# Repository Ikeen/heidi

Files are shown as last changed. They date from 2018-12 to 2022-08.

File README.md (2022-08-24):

# heidi heidi logo Heidi
GPS tracking system for alpine pasture - or simply sheeps :-)

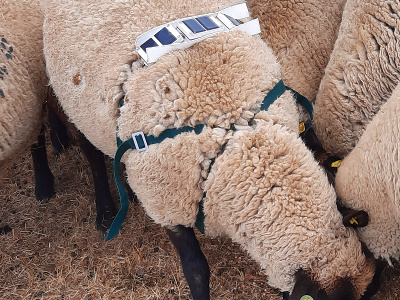
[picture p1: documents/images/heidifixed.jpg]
heidi fixed Heidi


## Table of contents
* [Licence info](#licence-info)
* [Project](#project)
* [Milestones](#milestones)
* [Solutions](#solutions)
* [News](#news)

## Licence info

You may freely use or copy this project under the following conditions:

* non-commercial use
* no warranties
	
## Project

The project goal:

* creating a tracker system from scratch
* using free available cheap standard electronic components
* 3D printable housings
* with in situ solar power generation for continuous operation
* vitality monitoring
* local LoRa network with client tracker modules for individual animal monitoring
	
## Milestones

* functional prototype - done
* CAD work for housings - done 
* initial web service - done
* 1st gateway tracker module for testings - done
* endurance tests for housing, power supply and modul reliability - done
* 1st client tracker module for testings - done
* endurance tests for lokal LoRa netwok reliability (gateway tracker <-> client trackers) - done
* accelerometer for vitality monitoring - done
* geofencing functionality - done
* store configuration data into flash memory - tbd
* tool for programming configuration data into flash memory - tbd

## Solutions

some solutions to various problems

* sending data via GSM cause Arduino to crash: Try another orientation of GSM-antenna. Sometimes a piece of copper acts like a receiving antenna, what may have an impact on the Arduino board.
* sending / getting data via GSM is unreliable: Check power connection to battery, MOSFET, DC-DC-Converter - they should be strong. In my case I soldered wires directly to IC-pins.
* serial communication between components produces strange characters: internally pullup RX-wire with "pinMode(_RXD, INPUT_PULLUP);". The HardwareSerial library seems not to do that. Most time it works without dedicated pullup - sometimes it doesn't.
* never place GSM-antenna and DC-DC-converter near by together

## News

* after various problems with communication reliability - especially with low battery - we find out, that placing a additional big capacitor on the power input of the DC-DC-converter, solves a buck of problems. It seems we can even omit the backup battery when we do so - but the DC-DC-converter is still needed. The SIM800L module will not work properly with less then 3.8V - even if the manual tells: it will.
* the fixing via belt clip turned out to be not reliable. We went back to the first intended fixing by screwing the hard plastic parts directly to a belt. Description and pictures coming soon on this channel.
* the buffer battery on the GPS module empties within a few days due to the way we use it. Let me explain a little more: keep the GPS module in power save tracking mode will give us quick results (saving time saves power) but it still draws about 10mA, way too much - so we completely cut it off from power. Usually the buffer battery enables the module to backup some information about the last position lock. These information eases and speeds up the next position lock. Unfortunately the battery is weak and its charging to slow, so it will be discharged after a couple of days. Removing the Battery from module and connecting the backup-pin of the UBLOX to 3.3V from Arduino will solve that problem and we will significantly profit from the backup function. The backup draws about 15uA - no problem. Assembly instructions and sketches will be updated soon. (done)
* the battery solar charging modules in Heidi hardware version 1 and 2 have one or two small big problems: if they are, for what reason ever, shortly disconnected from battery, sometimes they may be unable to reconnect the load to the battery. Furthermore their thresholds of hysteresis (deep discharge protection) are too low, so if the voltage goes too low ESP32 will boot in a circle until the modules cut off from load due to under voltage. So far so good, but in case of recharged batteries they will reconnect the load too early, so the ESP32 will directly starts with booting in a circle until the voltage is too low again. We've decided to implement a own protection circuit which cuts off on 2.7V and reconnects on 3.0V. That will keep the ESP32 in save states. Additionally that means, we can use Modules without under voltage protection. BUT: Doing this we loose short circuit protection too. We strongly recommend batteries with included protection PCB. (no barbecue on pasture!)

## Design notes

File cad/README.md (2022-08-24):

# heidi - cad
Some CAD- and 3D-printing hints

## Table of contents
* [CAD](#cad)
* [3D-printing](#3d-printing)
  * [Printing direction](#printing-direction)
  * [Dealing with ASA-filament](#dealing-with-asa-filament)
  * [Warping](#warping)
  * [Solutions](#solutions)
  * [Notes](#notes)
* [Schmitt-Trigger](#schmitt-trigger)
  * [KiCad](#kicad)
  * [Get a PCB](#get-a-pcb)
  * [Electronic parts](#electronic-parts)

## CAD
All CAD was done with [FreeCad](https://www.freecad.org/). All CAD project files are uploaded too (*.fcstd).

## 3D-printing
For our purposes we decided to use 3D print for building up housings. This is flexible and cost efficient. For more reliability against weather and mechanical stress it would be better to use housings milled from the solid material. There are good offers for 3-axis CNC mills - maybe we will test this later on. (It seems we seriously need to talk to Santa regarding this. :-D )
### Printing direction
For mechanical reasons you need to consider printing direction. 3D printed objects do have less mechanical strength in vertical printing direction, so the orientation of objects during printing process matters. You may use the models or *.stl files with number 3 in the file name to get models already ready for printing. Most of them are doubled and connected by thin walls, to get a stable printing process.
### Dealing with ASA-filament
The outdoor usage of Heidi-Tracker requires a weather proofed housing material. We decided for ASA-filament from PolyMaker (for no special reasons). If you not own a industrial like 3D-printer, printing ASA-filament is not quite simple. The temperature for the material nozzle and the build plate (bed) needs to be adjusted depending on the geometry of the part you intend to print. (As far as we discovered due to many tries.)
### Warping
[(warping - see here)](https://support.ultimaker.com/hc/article_attachments/360009279100/How_to_fix_warping_Warping_model.jpg)<br />
Warping is the main issue while printing ASA filament. There are many hints you can find in the internet to fix warping. 

### Solutions
some solutions to various problems
* to minimize warping you may use a frame, like the one in the picture below, together with at least 20 brim lines. 
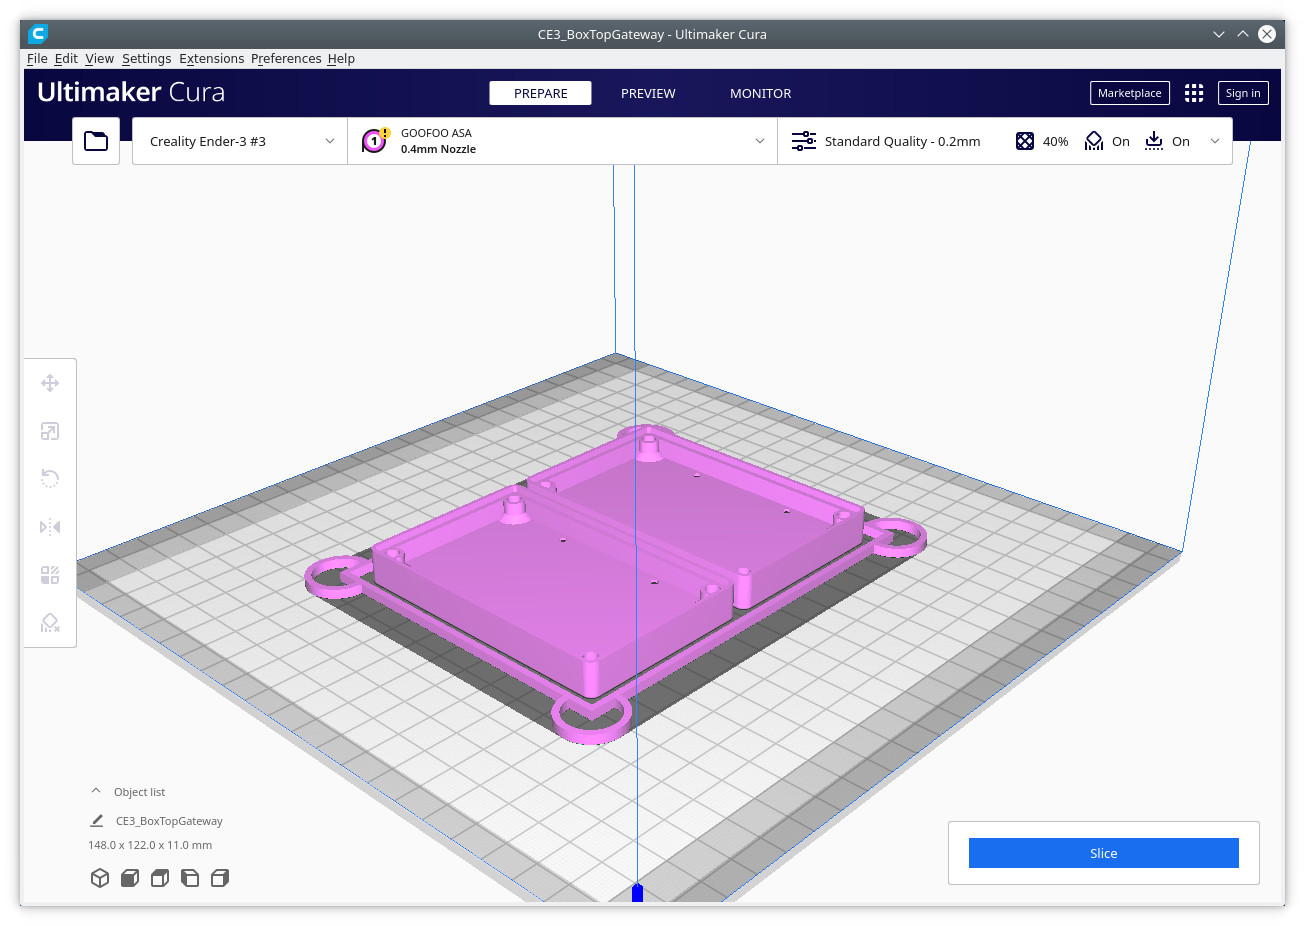
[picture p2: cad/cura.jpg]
Cura


### Notes
* There are slightly different sizes of GPS-antenna boards used. Currently GPSAntennaClip is for the bigger one (28mm edge length), GPSAntennaClip3 is for the smaller one (25mm edge length) 

## Schmitt-Trigger
As mentioned in the introducing README, the cut-off threshold of the battery protection circuits (2.4 volts) is too low and leads heidi into a dead lock if the voltage goes below 2.6 volts. Therefore we decided to create a own protection circuit, which cuts off at about 2.8 volts and brings heidi back to power at about 3.1 volts. That ensures, that the ESP32 works correctly (when empowered). (By the way: It's our first own PCB - it was a huge fun to research, learn to calculate a Schmitt-Trigger, to test, to explore new CAD-software...)

Keep in mind: You nevertheless need a battery protection circuit. The Schmitt-Trigger will continously draw a small current too. We decided to use LiPo batteries with [included protection](https://www.trustfire.com/collections/batteries/).

### KiCad
The software we're using for schematics an PCB layout is [KiCad](https://www.kicad.org). You find the project files unter /SchmittTrigger. 

### Get a PCB
The PCB has just one layer and no throughplatings - even for the power connections, what saves costs. The gerber files, needed for ordering PCBs online, are in the zip file. We've ordered the PCB [here]( https://aisler.net) -  good price, quick service. 

### Electronic parts
Be sure to use a dual channel rail to rail operational amplifier with a minimum operation voltage of 2.7 volt. Keep an eye on its supply current - it should be less as possible. The P-channel FET is a power-FET, but maybe another will do too, because there are just a few milliamps to manage.

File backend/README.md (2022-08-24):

# heidi-backend
We're (still) working with Eclipse 2018-12 (4.10.0) and the (old 1.0.5) CDT-libraries by espressif. You can find the reason [here](https://github.com/frankheisig71/TestAccel).
So here you will find the instructions to setup Eclipse 2018 with Arduino-CDT libraries on a Linux machine to build the heidi firmware. You are free to use another dev environment or other versions and to adopt the installation steps.

## Table of contents
* [Install Eclipse](#install-eclipse)
* [Install ESP32 core libs](#esp32-core-libs)
* [Install tool chain](#toolchain)
* [Edit platform.txt](#platform.txt)
* [Change Java version](#java)
* [Add ESP32 libs](#esp32-libs)
* [Enable phyton-serial](#phyton-serial)

## Install Eclipse
* Get Eclipse 4.10 from
https://archive.eclipse.org/eclipse/downloads/drops4/R-4.10-201812060815/ and install it to a directory of your choice.
* Start the executable.
* go to Help -> Install New Software, press "Add" and install download.eclipse.org/mpc/photon as a new repository.
* after downloading, check the selection box -> Next -> Next -> accept -> Finish (installation may take some time)
* restart Eclipse
* go to Help -> Eclipse Marketplace, search for "espressif"
* install "Eclipse C++ IDE for Arduino" (be patient)

## Install ESP32 core libs
* get https://github.com/espressif/arduino-esp32/releases/download/1.0.5/esp32-1.0.5.zip
* copy zip content to ~/.arduinocdt/packages
* get https://github.com/espressif/arduino-esp32/releases/download/1.0.5/package_esp32_index.json and put it to ~/.arduinocdt

## Install tool chain
* check the needed toolchain by opening package_esp32_index.json and searching "platforms": -> "architecture": "esp32", "version": "1.0.5" -> "toolsDependencies" -> "name". In our case it is:  "xtensa-esp32-elf-gcc". Note the needed version. For our case it is: "1.22.0-97-gc752ad5-5.2.0".
* now find the link to the toolchain for your operating system by searching for '"tools": ['. Find the right toolchain ("name") with the right version ("version") -> find the right operating system. For our case it is: ""x86_64-pc-linux-gnu"
* get the package following the link under "url". For our case it is: "https://github.com/espressif/arduino-esp32/releases/download/1.0.5-rc5/xtensa-esp32-elf-linux64-1.22.0-97-gc752ad5-5.2.0.tar.gz"
* extract the tar archive - next we need to copy the content of the root folder from the extracted archive, WITHOUT the root folder
* copy the content to ~/.arduinocdt/packages/esp32/tools/%name%/%version%. For our case it is: ~/.arduinocdt/packages/esp32/tools/xtensa-esp32-elf-gcc/1.22.0-97-gc752ad5-5.2.0/
* do exact the same steps the other toolsDependencies under "platforms": (In our case: "esptool_py" and "mkspiffs") with similar path name structure
* check the symlinks under ~/.arduinocdt/packages/esp32/tools/%name%/%version%/xtensa-esp32-elf (usually they are okay)

## Edit platform.txt
* open ~/.arduinocdt/packages/esp32/esp32/hardware/esp32/1.0.5/platform.txt
* seach for: `## Create partitions.bin`
* comment out: `recipe.objcopy.partitions.bin.pattern={tools.gen_esp32part.cmd} -q "{build.path}/partitions.csv" "{build.path}/{build.project_name}.partitions.bin"`
* insert: `recipe.objcopy.eep.pattern={tools.gen_esp32part.cmd} -q "{runtime.platform.path}/tools/partitions/{build.partitions}.csv" "{build.path}/{build.project_name}.partitions.bin"`
* seach for: `runtime.tools.xtensa-esp32-elf-gcc.path =`
* if found, change it to: `runtime.tools.xtensa-esp32-elf-gcc.path = ~/.arduinocdt/packages/esp32/tools/xtensa-esp32-elf`
* seach for: `runtime.tools.esptool.path =`
* if found, change it to: `runtime.tools.esptool.path = ~/.arduinocdt/packages/esp32/tools/esptool`

## Change Java version
* java version for Eclipse 2018 is 1.11
* open eclipse.ini search for: `-vmargs`
* add or change before `-vmargs`: <br>
  `-vm`<br>
  `/usr/lib/jvm/java-1.11.0-openjdk-amd64/bin/java`
* (... or whereever java is installed)

## Add ESP32 libs
* Open Eclipse and go to Help -> Arduino Downloads Manager -> Libraries

For Heidi we need:

* ESP8266 and ESP32 OLED driver for SSD1306 displays
* LoRa
* OneWire
* DallasTemperature
* FEC Reed-Solomon

## Enable phyton-serial
Linux users need to put themselves into the dialout group
* `sudo apt install python-serial`
* `sudo adduser [user] dialout`

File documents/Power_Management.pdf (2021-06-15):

Power management of the Heidi tracker

The Arduino is powered by 2 batteries. On one hand the regular board voltage supply and on the other hand a backup battery, which prevents a brown-out of the Arduiono due to voltage drops caused by the high peak currents of the GSM module from a board voltage of Ubatt < approx. 3.8V. Both supply lines are connected via a current switch, 2 Schottky diodes. This circuit leads to a equal voltage discharging of both batteries. .

So the Arduino gets its supply voltage via 1 Schottky diode of type 1N5817 each. This diode has a voltage loss of about 0.3V in forward direction, which means that Ubatt - 0.3V arrives at the Arduino.

The ESP32 works correctly down to about 2.6V, as far as no internal consumers like GPIO's need additional current. As soon as the power consumption increases just a little bit, a brownout reset may occur (a big capacitor does not change this bevavior).

In the range below 2.6V the behavior of the ESP32 is undetermined - it boots in a circle.

The deep discharge protection of the solar loader modules cuts the load from the batterie at Ubatt < 2.4V and switches it on again at Ubatt ≥ 3.0V.

The following voltage limits are fixed:

- Ubatt ≥ 3,6V | – normal function
- 3,6V > Ubatt ≥ 3,5V – doubled times between regular data transmissions, alarms
| normal
- 3,5V > Ubatt ≥ 3,4V – no regular data transmissions, alarms normal
- Ubatt < 3,4V | – deep sleep for 15 minutes
- Ubatt < 3,3V | – deep sleep for 60 minutes

The aim of the power management is to be able to send alarms as long as possible when the batteries are underpowered and to avoid a supply voltage of the Arduino below 2.6 V later on.

From 3.5 V battery voltage the battery has only very small energy content. Therefore the regular transmission of data is stopped. Alarms are not sent from 3.4 V, because the voltage drops may cause that the transmission fails.

To avoid the relatively fast discharge of the battery at the range from Ubatt < 2.8 V to Ubatt < 2.4 V, a Schmitt-trigger circuit with appropriate hysteresis can be installed for a cut off of the Arduino from Ubatt < 3.0V.

Extreme low-supply scenario:

Pos | Ubatt | Operating status | Charging status
1 | < 3,6 V | save power by doubling the time between data transfers
2 | < 3,5 V | data transmissions are stopped (measurements continue), only alarms are sent (with transmission of the location)
3 | < 3,4 V | no more activities, check battery status every 15 minutes
4 | < 3,3 V | no more activities, check battery status every 60 minutes
5 | < 3,0 V | the ESP32 triggers a brown-out reset when checking the battery status, the brown-out is detected during the next boot process and a deep sleep of 60 minutes is set.
6 | < 2,8 V | the ESP32 boots in a circle and consumes 30 mA permanently, the battery is further discharged
7 | < 2,4 V | the charge controller of the battery cuts off all loads
8 | > 2,4 V | the charge controller of the battery keeps all loads cut off.
9 | > 3,0 V | charge controller of the battery turns back on all loads → position 5 - the ESP32 boots at least in a controlled manner
10 | > 3,3 V | → position 4
.. | .. | etc.

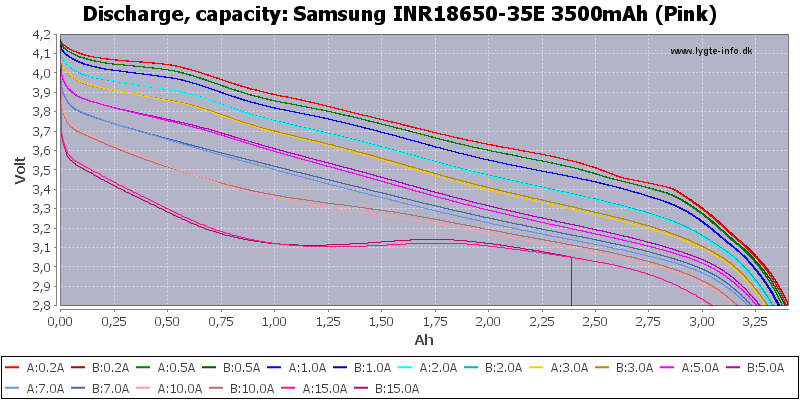
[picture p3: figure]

Abbildung 1: source: https://lygte-info.dk

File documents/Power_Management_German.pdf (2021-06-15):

Power-Management des Heidi-Trackers

Der Arduino wird von 2 Akkus versorgt. Das ist einerseits die reguläre Bordspannungsversorgung und andererseits ein Stütz-Akku, der ab einer Bordspannung von Ubatt < ca. 3,8V dafür sorgt, dass die Spannungseinbrüche, verursacht durch die hohen Spitzenströme des GSM-Moduls, nicht zu einem Brown-Out des Arduiono führen. Beide Versorgunggstränge sind über eine Stromweiche, 2 Schottky-Dioden, zusammengeführt. Diese Schaltung sorgt dafür, dass beide Akkus beim Entladen immer das gleiche Spannungsniveau haben.

Der Arduino bezieht also seine Versorgungsspannung über je 1 Schottky-Diode Typ 1N5817. Diese hat einen Spannungsverlust von etwa 0,3V in Durchlassrichtung, das heißt am Arduino kommt Ubatt – 0,3V an.

Der ESP32 arbeitet bis etwa 2,6V korrekt, soweit keine internen Verbraucher wie GPIO‘s zusätzlichen Strom benötigen. Sobald sich der Strombedarf erhöht, kann es zu einem Brownout-Reset kommen (ein Puffer-Kondensator ändert daran nichts).

Im Bereich unter 2,6V Ist das Verhalten des ESP32 unbestimmt – er bootet im Kreis.

Der Tiefenentladeschutz der Lademodule schaltet die Versorgung erst bei Ubatt < 2,4V ab und erst bei Ubatt ≥ 3,0V wieder zu.

Folgende Spannungsgrenzen sind fest eingestellt:

- Ubatt ≥ 3,6V | – normale Funktion
- 3,6V > Ubatt ≥ 3,5V – verdoppelte Zeiten zwischen den regulären
| Datenübertragungen, Alarme normal
- 3,5V > Ubatt ≥ 3,4V – keine regulären Datenübertragungen, Alarme normal
- Ubatt < 3,4V | – deep sleep 15 Minuten
- Ubatt < 3,3V | – deep sleep 60 Minuten

Ziel des Power-Management ist es, bei Unterversorgung der Akkus so lange wie möglich Alarme senden zu können und später eine Versorgungsspannung des Arduino von unter 2,6 V zu vermeiden.

Ab 3,5 V Batteriespannung hat der Akku nur noch sehr wenig Energiegehalt. Deshalb wird die reguläre Übertragung der Daten eingestellt. Alarme werden ab 3,4 V nicht mehr abgesetzt, da die Spannung dabei so stark einbricht, dass die Übertragung nicht sicher gewährleistet ist.

Um das relativ schnelle Entladen des Akkus bei Ubatt < 2,8 V auf Ubatt < 2,4 V zu vermeiden, kann eine Schmitt-Tigger-Schaltung mit entsprechender Hysterese für eine Abschaltung des Arduino ab Ubatt < 3,0V eingebaut werden.

Extremes Unterversorgungs-Szenario:

Pos | Ubatt | Betriebszustand | Ladezustand
1 | < 3,6 V | Strom sparen durch Verdopplung der Zeitspanne zwischen den Datenübertragungen
2 | < 3,5 V | Einstellung der Datenübertragungen (messungen laufen weiter), nur noch Alarme werden abgesetzt (mit Übertragung des Standorts)
3 | < 3,4 V | keine Aktivitäten mehr, alle 15 Minuten Überprüfung des Batteriezustandes
4 | < 3,3 V | keine Aktivitäten mehr, alle 60 Minuten Überprüfung des Batteriezustandes
5 | < 3,0 V | Der ESP32 löst bei der Überprüfung des Battriezustandes einen Brown-Out-Reset aus, beim nächsten Bootvorgang wir der Brown-Out erkannt und ein Deep-Sleep von 60 Minuten ausgesöst
6 | < 2,8 V | Der ESP32 bootet im Kreis und verbraucht dabei dauerhaft 30 mA, der Akku wird weiter entladen
7 | < 2,4 V | Der Laderegler des Akkus schaltet alle Lasten ab
8 | > 2,4 V | Der Laderegler des Akkus schaltet alle Lasten weiterhin ab
9 | > 3,0 V | Der Laderegler des Akkus schaltet alle Lasten wieder zu → Position 5 – der ESP32 bootet zumindest kontrolliert
10 | > 3,3 V | → Position 4
.. | .. | usw.


Abbildung 1: Quelle: https://lygte-info.dk

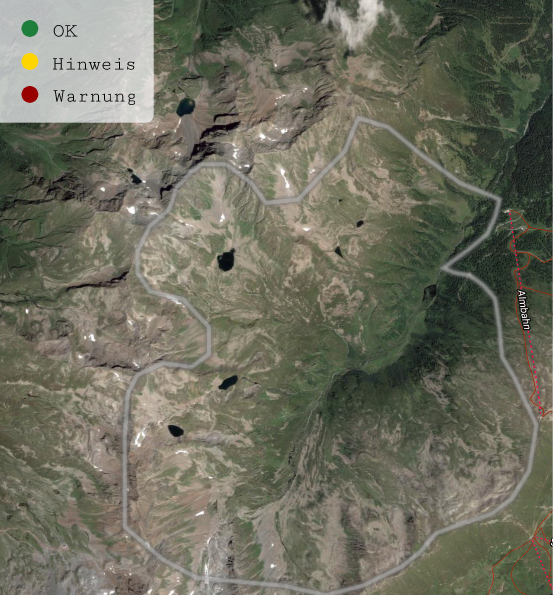
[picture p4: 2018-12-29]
frontend/img/overview.png

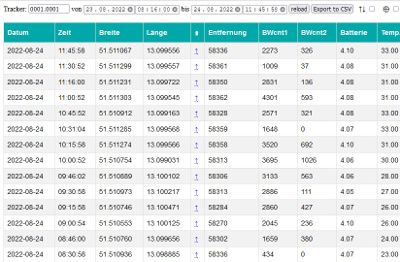
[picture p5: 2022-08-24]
documents/images/heididata.jpg

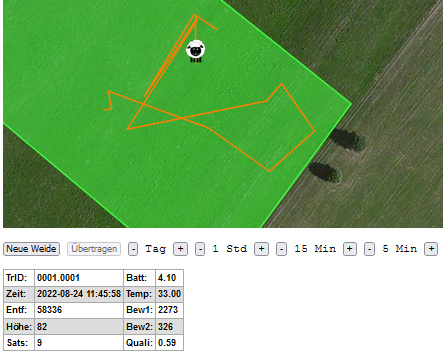
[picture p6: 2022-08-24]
documents/images/heidimap.jpg

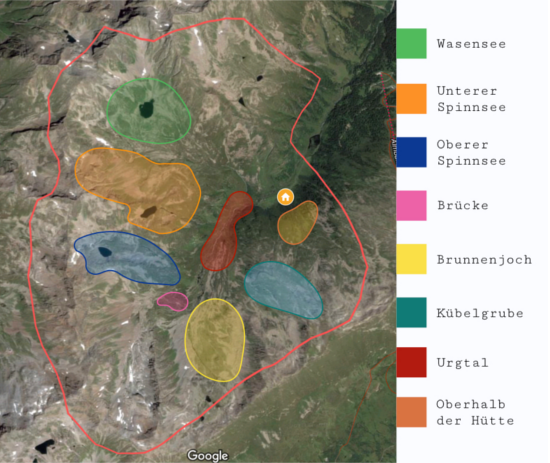
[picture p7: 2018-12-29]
frontend/img/map.png

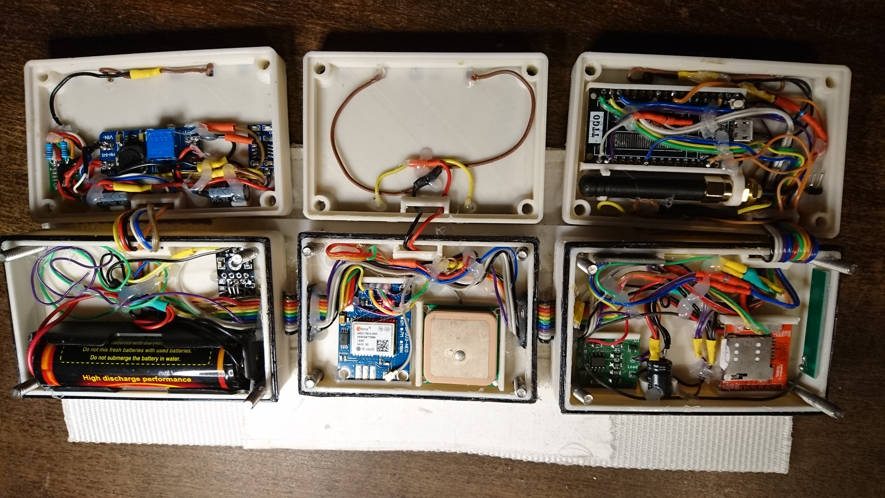
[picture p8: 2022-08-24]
documents/images/heidiopen.JPG

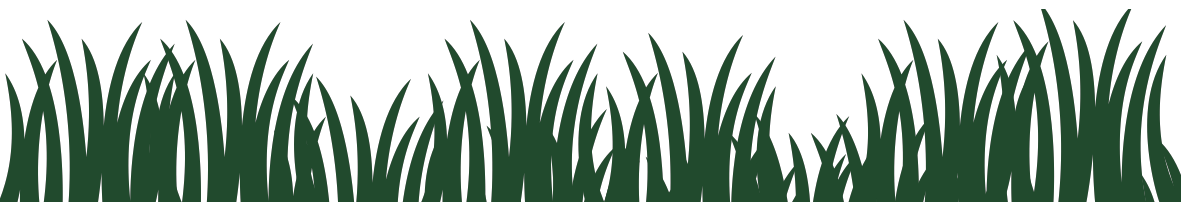
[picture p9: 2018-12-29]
frontend/img/gras.png

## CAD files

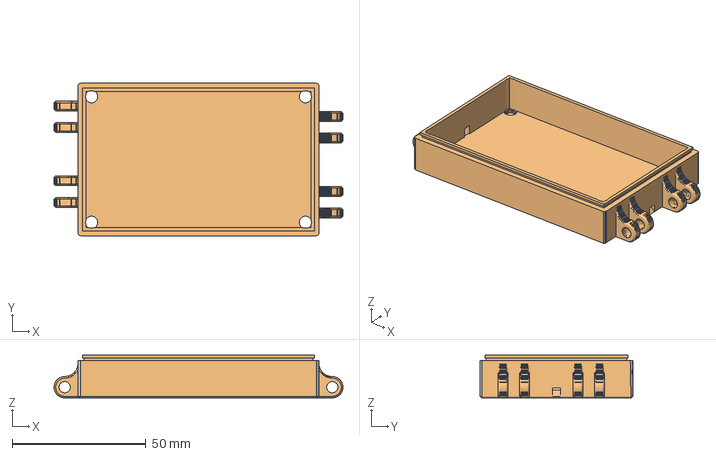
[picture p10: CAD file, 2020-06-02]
cad/ClientTracker/BoxBottomClient.fcstd
108.0 x 57.0 x 16.0 mm
Cut014 (Meshed)

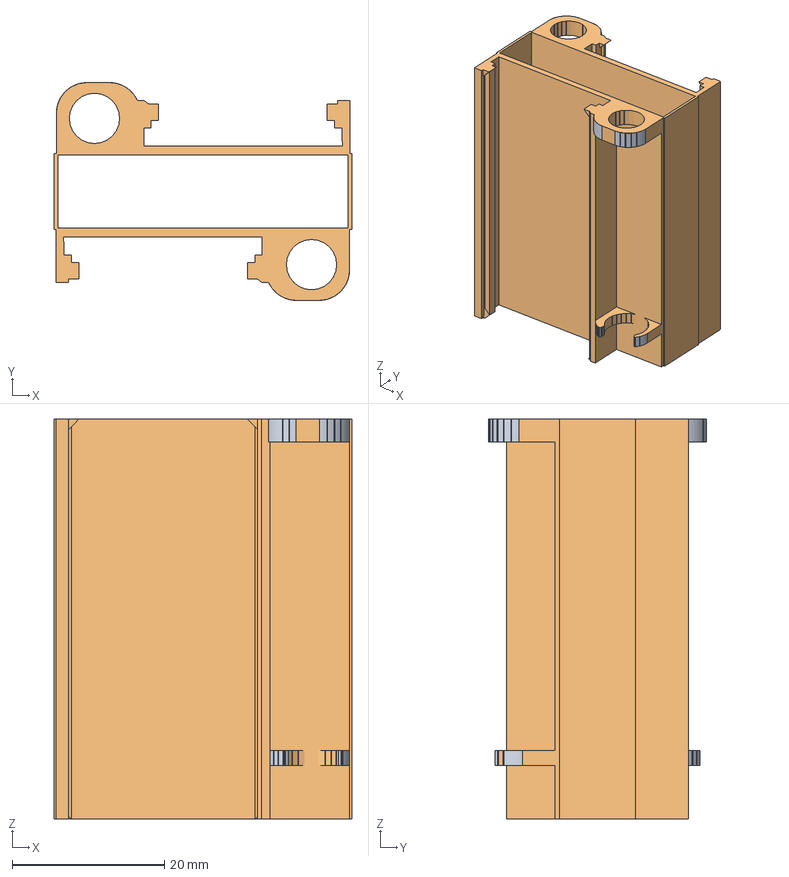
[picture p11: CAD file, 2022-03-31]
cad/Clips/ArduinoClip3.fcstd
39.1 x 28.6 x 52.5 mm
Fusion002 (Meshed)

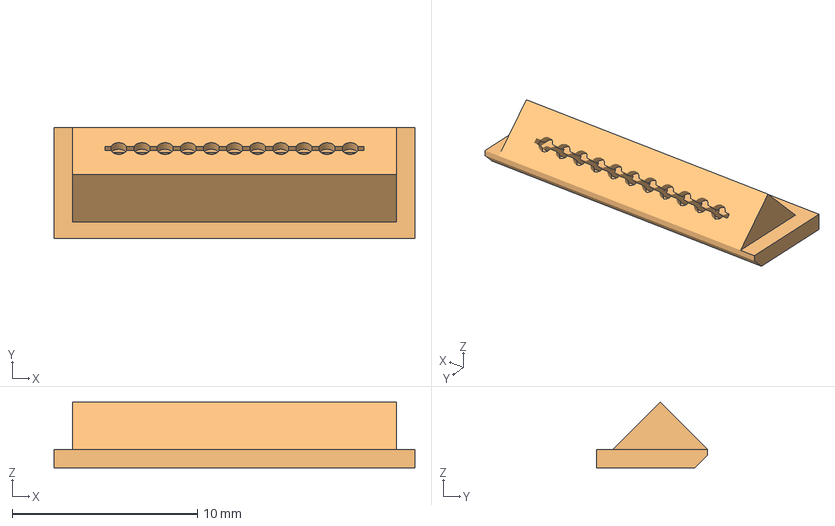
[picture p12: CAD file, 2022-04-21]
cad/Gaskets/CableGasket.fcstd
19.5 x 6.00 x 3.54 mm
Cut005 (Meshed)

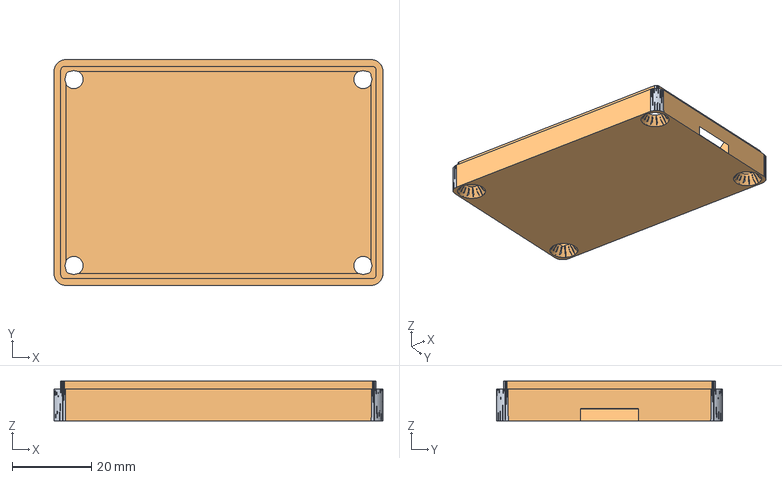
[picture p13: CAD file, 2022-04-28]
cad/GatewayTracker/MidBoxBottom.fcstd
83.0 x 57.0 x 10.0 mm
Fillet001 (Meshed)

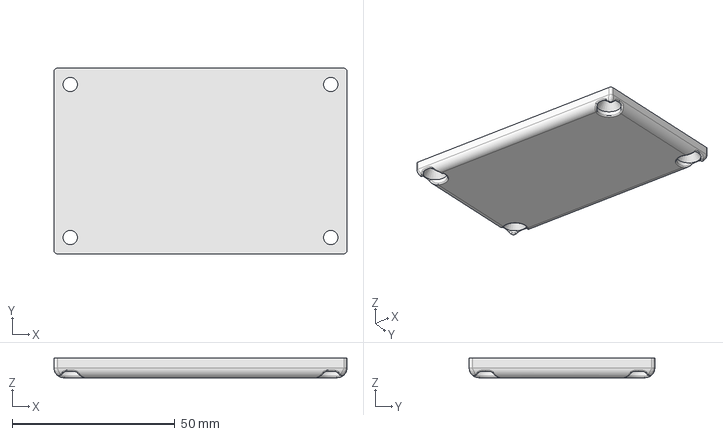
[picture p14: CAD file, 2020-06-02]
cad/ClientTracker/BoxBeltClipClient.fcstd
90.0 x 57.0 x 6.00 mm

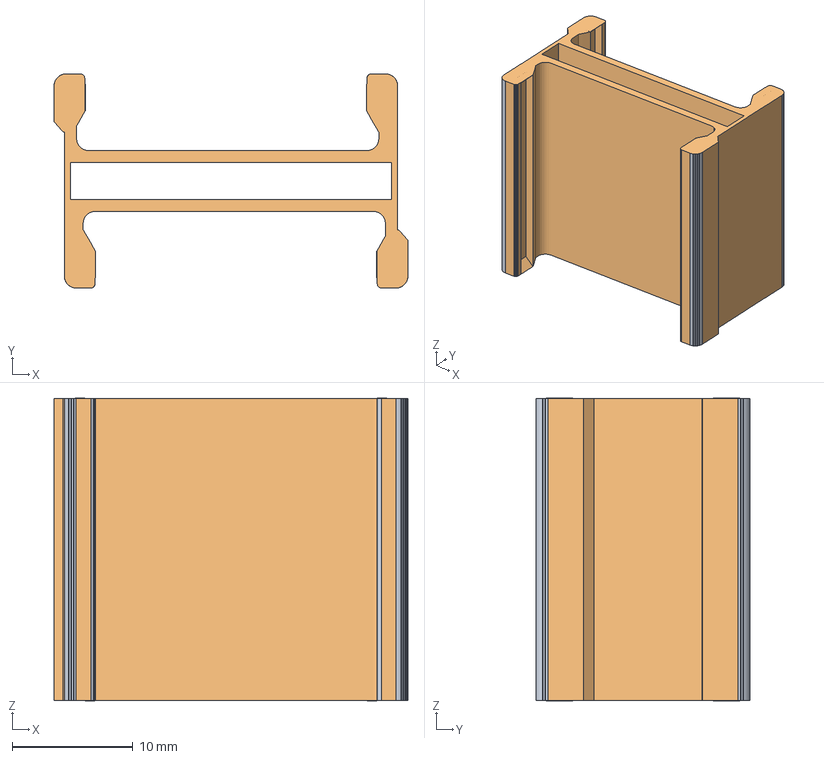
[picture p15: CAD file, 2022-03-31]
cad/Clips/GSMBoardClip3.fcstd
29.3 x 17.7 x 25.0 mm
Fusion006 (Meshed)

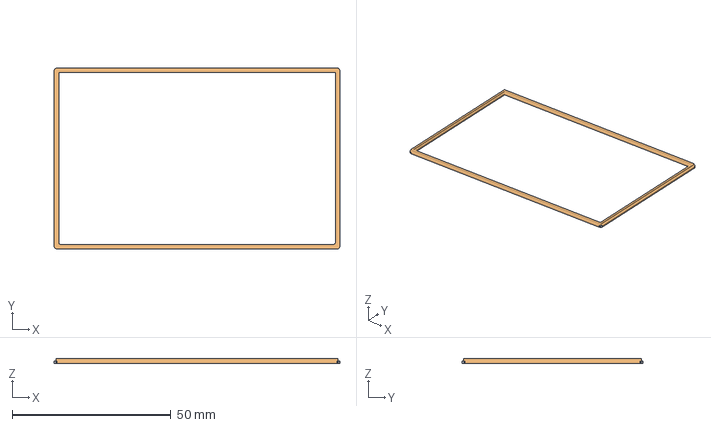
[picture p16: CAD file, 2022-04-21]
cad/Gaskets/BoxGasket.fcstd
90.0 x 57.0 x 1.50 mm
Fusion (Meshed)

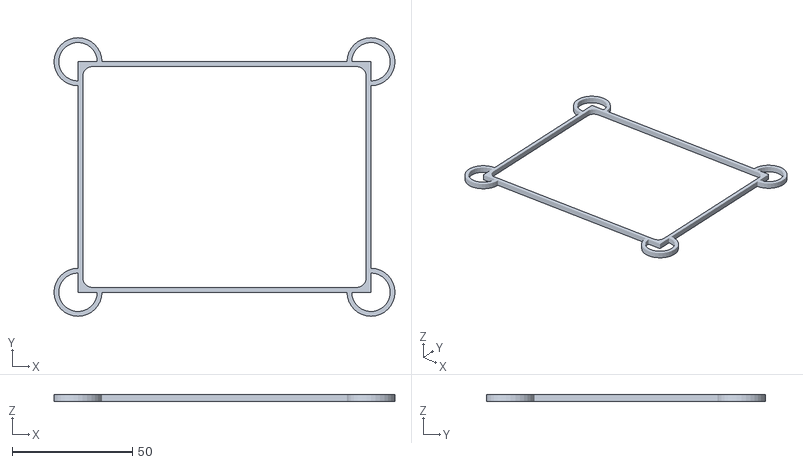
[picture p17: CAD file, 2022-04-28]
cad/GatewayTracker/PrintingFrameBox.stl
142.0 x 116.0 x 3.00

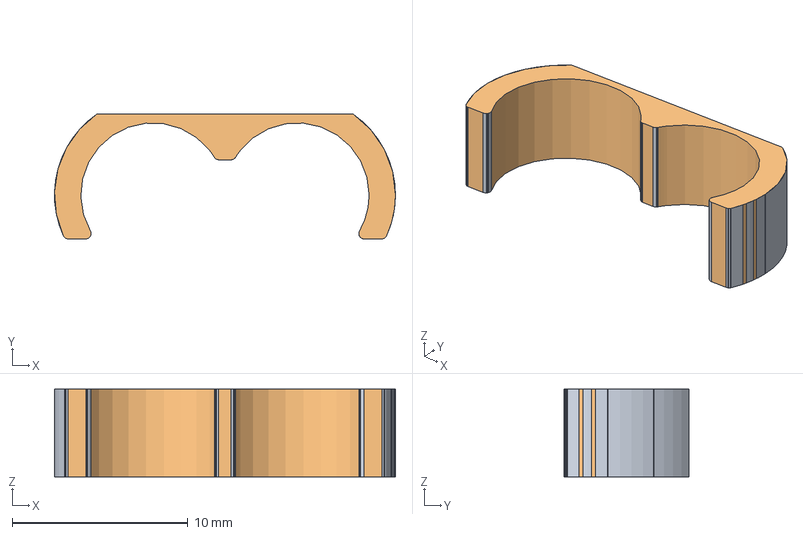
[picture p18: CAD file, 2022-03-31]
cad/Clips/CapClip3.FCStd
19.4 x 7.10 x 5.00 mm
Cut004 (Meshed)

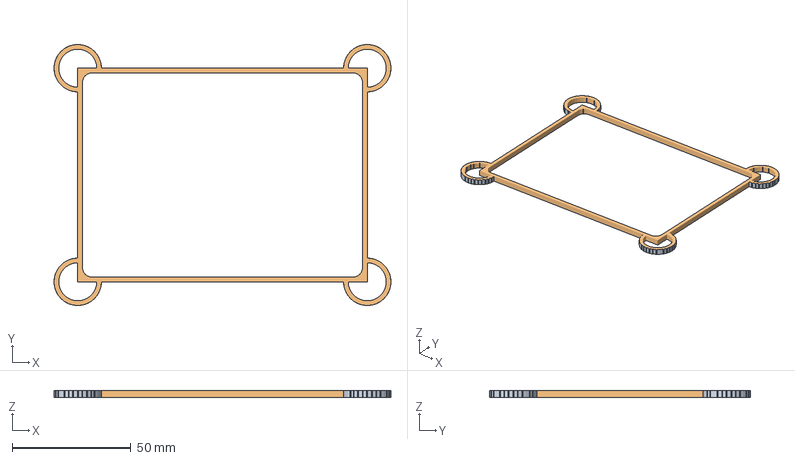
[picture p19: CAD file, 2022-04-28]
cad/GatewayTracker/PrintFrameMidBox.FCStd
142.0 x 110.0 x 3.00 mm
Fillet (Meshed)

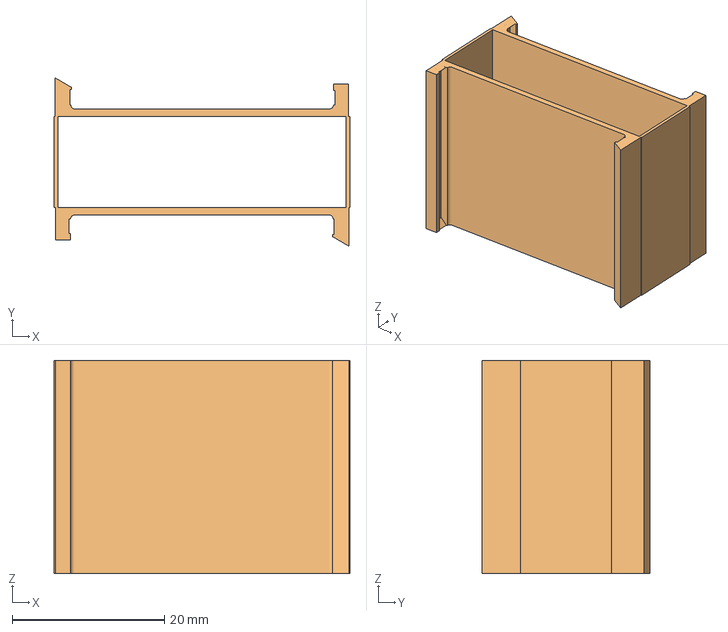
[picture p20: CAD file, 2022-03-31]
cad/Clips/GPSBoardClip3.fcstd
38.9 x 22.1 x 28.0 mm
Fusion002 (Meshed)

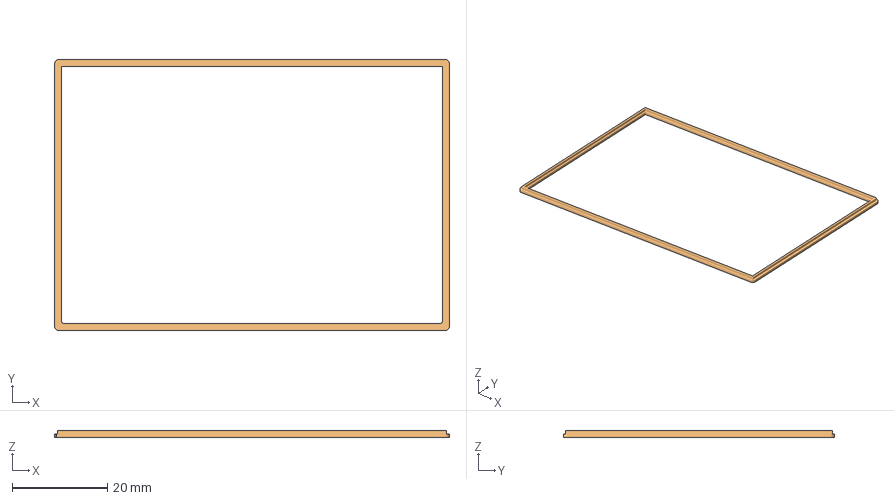
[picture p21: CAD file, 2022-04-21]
cad/Gaskets/SmallBoxGasket.fcstd
83.0 x 57.0 x 1.50 mm
Fusion (Meshed)

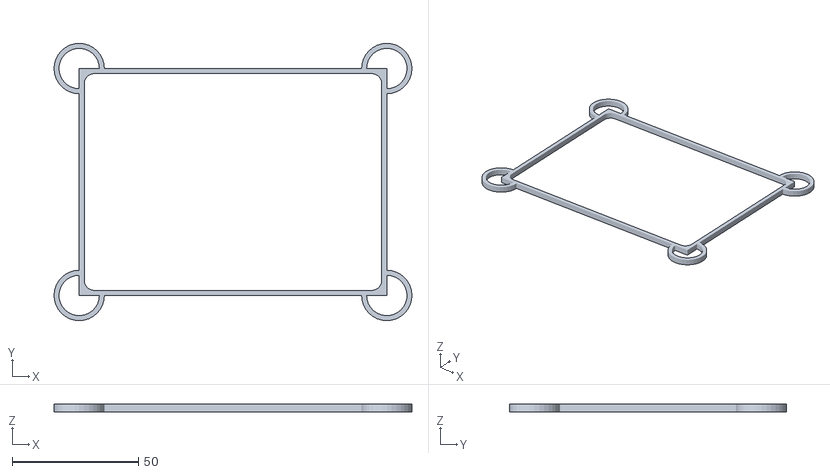
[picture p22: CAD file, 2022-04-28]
cad/GatewayTracker/PrintingFrameMidBox.stl
142.0 x 110.0 x 3.00

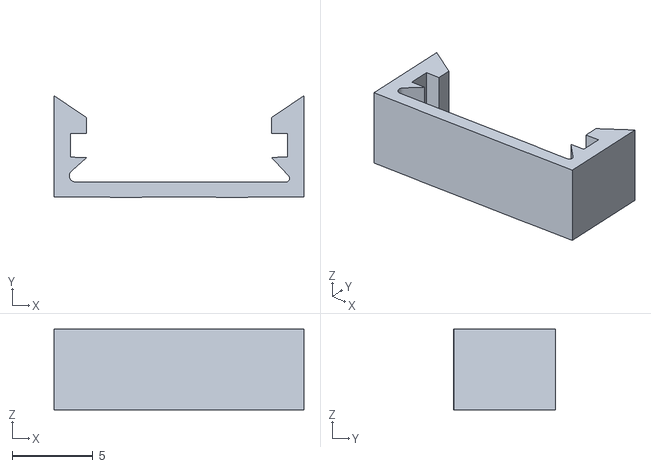
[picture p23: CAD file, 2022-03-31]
cad/Clips/13mmBoardClip.stl
15.5 x 6.30 x 5.00

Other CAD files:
cad/GatewayTracker/PrintFrameBox.FCStd
cad/Clips/GPSBoardClip.fcstd
cad/GatewayTracker/BoxBottomGateway.fcstd
cad/Clips/GSMBoardClip.fcstd
cad/ClientTracker/BoxBottomClient.stl
cad/Clips/12mmBoardClip.stl
cad/Clips/12mmClip.FCStd
cad/Clips/21mmBoardClip.stl
cad/Clips/21mmClip.FCStd
cad/Clips/AccelClip.stl
cad/Clips/ArduinoClip.fcstd
cad/Clips/ArduinoClip.stl
cad/Clips/ArduinoClip3.stl
cad/Clips/CableClip.fcstd
cad/Clips/CableClip.stl
cad/Clips/CableClip3.fcstd
cad/Clips/CableClip3.stl
cad/Clips/CapClip.FCStd
cad/Clips/CapClip.stl
cad/Clips/CapClip3.stl
cad/Clips/GPSAntennaClip.fcstd
cad/Clips/GPSAntennaClip.stl
cad/Clips/GPSAntennaClip3.fcstd
cad/Clips/GPSAntennaClip3.stl
cad/Clips/GPSBoardClip.stl
cad/Clips/GPSBoardClip3.stl
cad/Clips/GSMBoardClip.stl
cad/Clips/GSMBoardClip3.stl
cad/Gaskets/BoxGasket.stl
cad/Gaskets/CableGasket.stl
cad/Gaskets/ScrewGasket.fcstd
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

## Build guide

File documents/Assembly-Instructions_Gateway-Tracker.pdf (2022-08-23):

Assembly Gateway Tracker - Sheep variant

The housing parts are produced by 3D printing. ASA

filament must be used for the hard plastic parts in

order to obtain the strength and weather resistance

required. PLA is definitely not suitable!

The gaskets are produced from permanent-elastic

filament, e.g. SainSmart Flexible TPU.

Both types of filament mentioned are not entirely

easy in processing and require some experience.

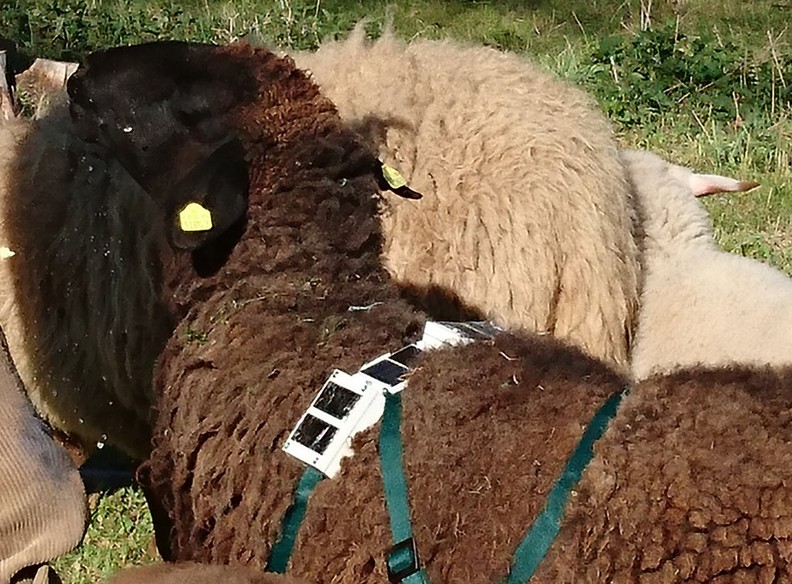
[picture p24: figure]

Housing individual parts - bottom cover for solar panel (DblSolarPltBottomCover) is missing

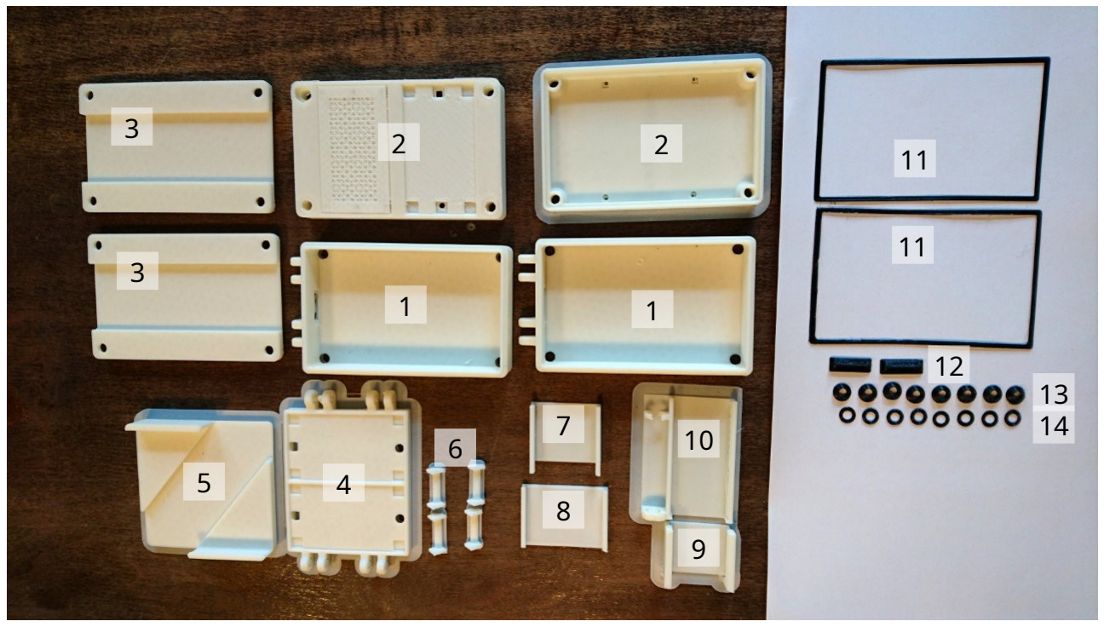
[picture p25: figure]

(1) Box bottom (BoxBottomGateway)
(2) Box top (BoxTopGateway)
(3) Box longitudinal belt guide (BoxBeltClipGateway) not used for V3
(4) Double solar panel (DoubleSolarPlate) replaced by a box for V3
(5) Solar panel cross belt guide (DoubleSolarPlateBeltClip) not used for V3
(6) Cable guide (CableClip)
(7) GPS antenna holder (GPSAntennaClip)
(8) GPS board mount (GPSBoardClip)
(9) GSM board holder (GSMBoardClip)
(10) Arduino board mount (ArduionoClip)
(11) Box gasket (BoxGasket)
(12) Cable tunnel gasket (CableGasket)
(13) Countersunk head gasket (ScrewHoleGasket)
(14) Screw gasket (ScrewGasket)
(15) bottom cover for solar panel (DblSolarPltBottomCover)

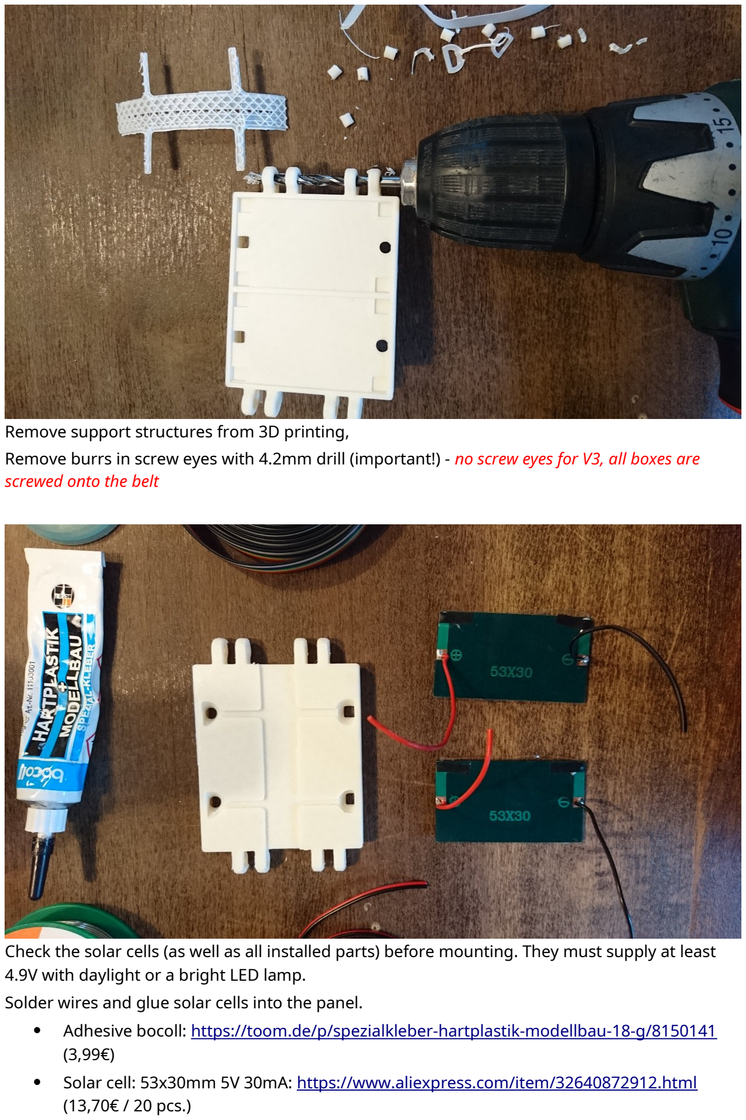
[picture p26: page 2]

Remove support structures from 3D printing,

Remove burrs in screw eyes with 4.2mm drill (important!) - no screw eyes for V3, all boxes are

screwed onto the belt

Check the solar cells (as well as all installed parts) before mounting. They must supply at least

4.9V with daylight or a bright LED lamp.

Solder wires and glue solar cells into the panel.

- Adhesive bocoll: https://toom.de/p/spezialkleber-hartplastik-modellbau-18-g/8150141

(3,99€)

- Solar cell: 53x30mm 5V 30mA: https://www.aliexpress.com/item/32640872912.html

(13,70€ / 20 pcs.)

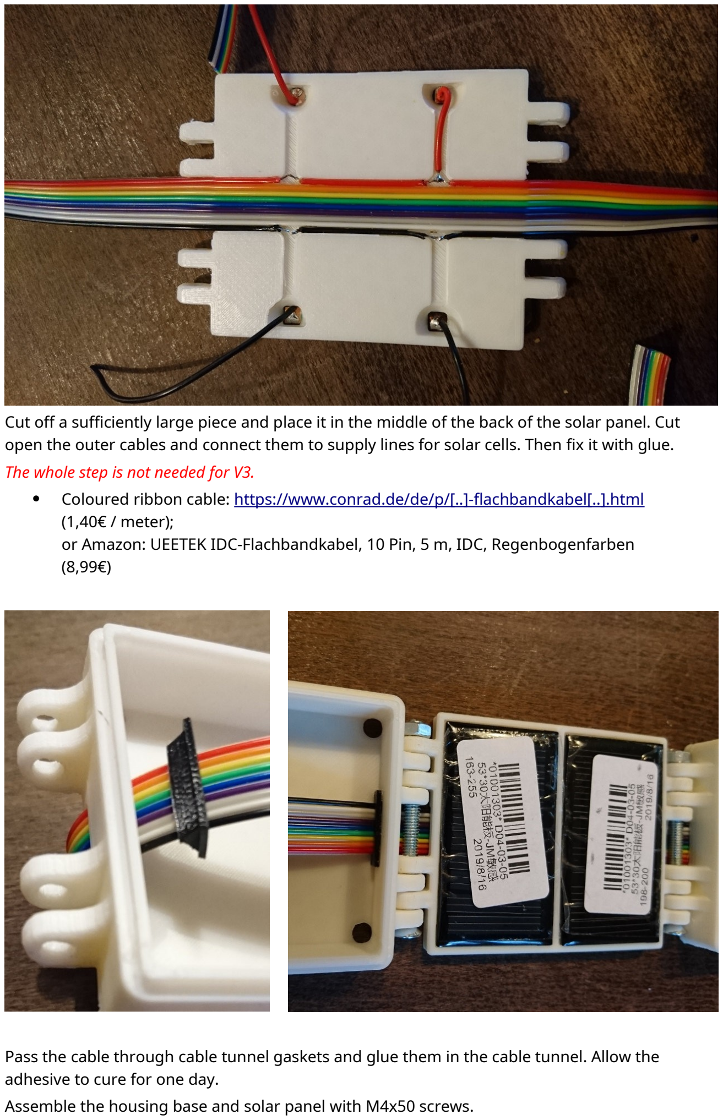
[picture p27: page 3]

Cut off a sufficiently large piece and place it in the middle of the back of the solar panel. Cut

open the outer cables and connect them to supply lines for solar cells. Then fix it with glue.

The whole step is not needed for V3.

- Coloured ribbon cable: https://www.conrad.de/de/p/[..]-flachbandkabel[..].html (https://www.conrad.de/de/p/bkl-electronic-10120156-flachbandkabel-rastermass-1-27-mm-10-x-0-08-mm-bunt-744224.html)

(1,40€ / meter);

or Amazon: UEETEK IDC-Flachbandkabel, 10 Pin, 5 m, IDC, Regenbogenfarben

(8,99€)

Pass the cable through cable tunnel gaskets and glue them in the cable tunnel. Allow the

adhesive to cure for one day.

Assemble the housing base and solar panel with M4x50 screws.

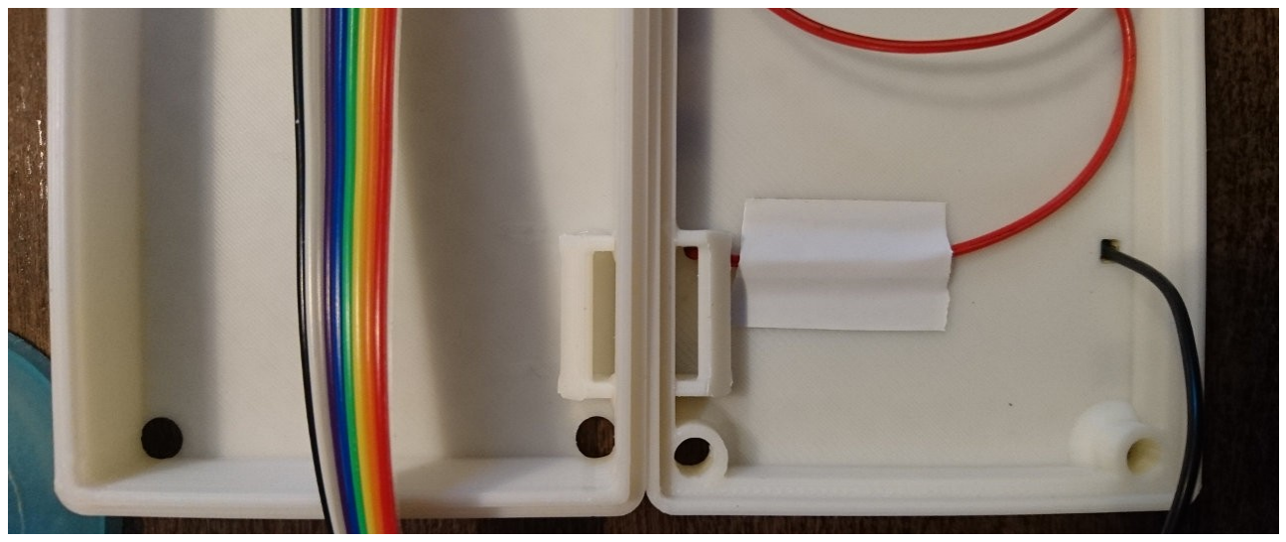
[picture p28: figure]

Glue the solar cells on the upper parts of the housing (similar as on the solar panel, but longer

supply lines)

Glue in cable guides - on different positions for each box, see the fully equipped housing parts

below. Allow the adhesive to cure for one day.

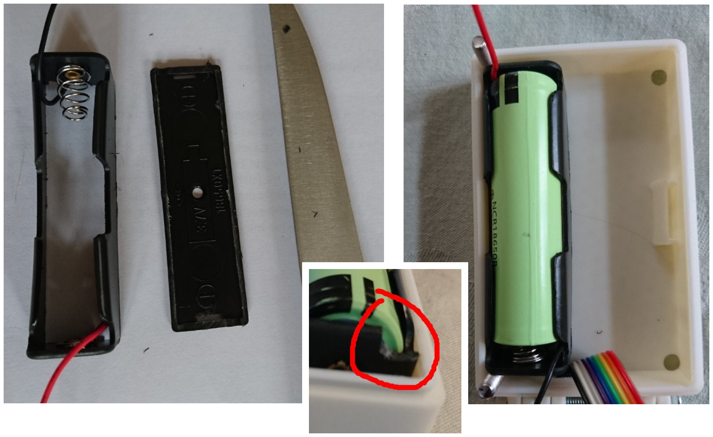
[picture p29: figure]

Check the contact of the supply line to the battery holder - sometimes it must be re-soldered

because the riveted joint is weak - up to 3A should flow over it later without major voltage drops.

Remove the bottom of the battery holder (1.5mm space gain), roughen the rear side surface and

glue in the battery holder with inserted battery and positioned housing screws. Removing the

bottom of the battery holder is not needed for V3.

Remove the outer end wall corners of the battery holder - they would overlap with the screw

domes (small picture)

- 18650 battery holder: https://www.aliexpress.com/item/4000445340785.html (0,30€ /

pcs.)

- 18650 Battery, Panasonic NCR18650B: many suppliers - do not buy too cheap (from

4,00€ upwards / pcs.)

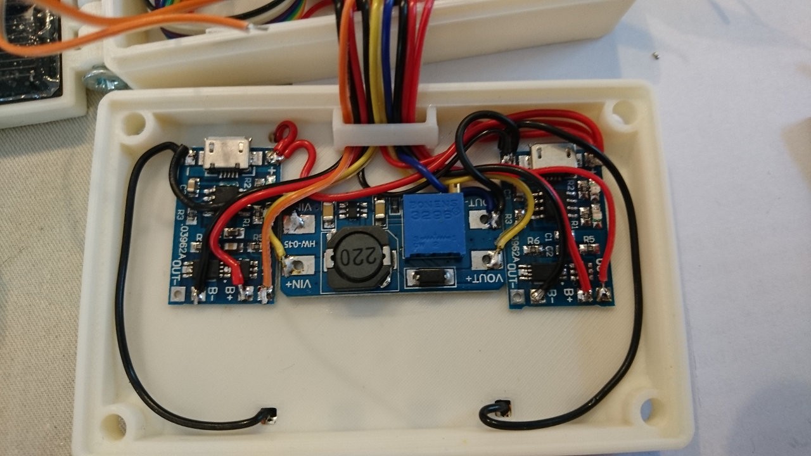
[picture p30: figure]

Glue the charging modules and the DC-DC converter into the upper part of the housing and wire

them according to the wiring diagram.

The DC-DC converter should be set to Uo=4 V before gluing in. Sometimes, the variable resistor

must be turned through 1x completely. There are additional caps for Version 3 near Vin and Vout of

the DC-DC converter. Take care to place them close.

In some cases, the contact wires of the push-through elements need to be sanded down on the

underside of the circuit boards. Take care for the space needed for the large battery. Connect

ground wires (blue/black) together.

- 2 x Micro USB 5V 1A 18650 TP4056 Lithium Battery Charger Module Charging Board With

Protection: https://www.aliexpress.com/item/32984862014.html (1,80€ / 10 pcs.)

- MT3608 DC-DC Step Up Converter Booster Power Supply Module Boost Step-up Board

https://www.aliexpress.com/item/32948417810.html (1,70€ / 5 pcs.)

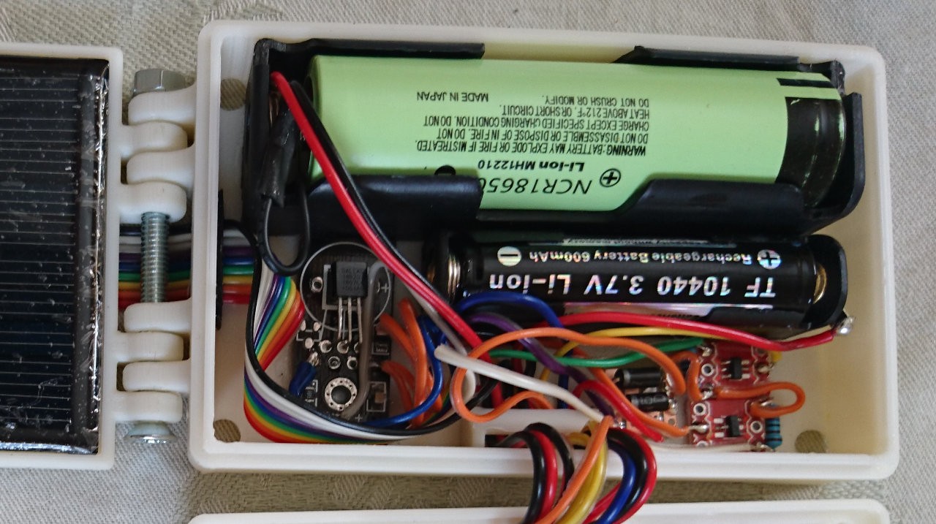
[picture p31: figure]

Roughen the AAA battery compartment and glue it in place with the battery inserted. The

TrustFire batteries are a bit too long due to the built-in protection circuit, but still fit and last.

Batteries without protection would also be possible, as the charging module offers sufficient

protection, e.g. AAA ICR 10440 at amazon. AAA-Battery is not needed for V3.

From bottom right to left: the MOSFETs on SOT23 circuit boards, the Schottky diodes on a grid

circuit board and the thermal sensor - wired according to the circuit diagram.

- BestPlug battery holder for Micro AAA Battery, amazon: (2,16€ / pcs.)
- TrustFire Li-Ion Battery 3,7V AAA, amazon: (7,99€ / pcs.)
- thermal sensor DS18B20 single-wire-bus digital temperature sensor module:

https://www.aliexpress.com/item/32242626689.html (0,80€ / pcs.)

- 2 x Schottky Diode 1N5817 Amazon: (4,99€ / 20 pcs.) - pay attention to low forward

voltage for alternative types

- MOSFETs - IRLML6402 SOT-23 Ultra Low On-Resistance P-Channel MOSFET, conrad:

(0,20€ / pcs.)

- SOT23 circuit boards, - MagiDeal 50 pcs. 6 pin SOT23 TO DIP Adapter pcb: amazon (3,99€

/ 50 pcs.)

- grid circuit board and resistors 4k7 0,25W: Conrad (2,89 € / 75 cm² and 0,07€ / pcs.)

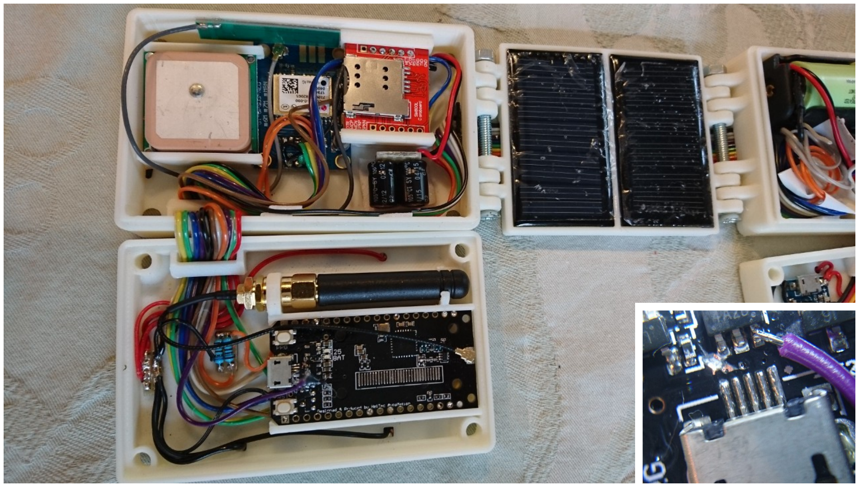
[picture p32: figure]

Install all electronic modules in the provided brackets and wire them according to the wiring

diagram. On the picture, the GPS module (top middle) is not glued in its holder, but directly to

the case - this is probably not a good idea due to the electrical characteristic of the glue and was

changed later.

The used Arduiono module (below) is a TTGO ESP32 SX1276 LoRa 868 MHz without OLED display

in version 1.0. Some remarks on this:

There are newer versions which do not need the hardware hack (see next paragraph) or which

may have GPS onboard. Nevertheless the "old" module was selected because it is much cheaper

and compact. Furthermore the position of the USB socket, the mounting of the LoRa antenna

and if necessary the mounting of the GPS antenna have to be considered - all in all the chosen

configuration is the most reasonable one at the moment (06/2020).

The hardware hack (small picture) is necessary because in this version of the board the USB

serial converter cannot be switched off and thus the quiescent current consumption is much too

high. Therefore, the power supply of this IC has been disconnected from the board voltage

(cutted track - from the left connector of the IC in the upper middle of the picture leading

diagonally left down between the USB connectors and the SMD resistor) and the power supply

has been soldered behind the disconnection (violet wire on the mentioned IC) - with connected

USB cable, the USB serial converter still works.

V3 uses Version 1.3 of the TTGO board – no hack needed.

A LoRa board is only needed if a local network with client trackers is to be used in the herd for

single animal monitoring. Otherwise any ESP32 Arduino board with similar features is suitable

(e.g. WEMOS ESP-32 Lite V1.0.0 Development Board, aliexpress: 3,50€).

When positioning the modules, pay attention to the cable routing, metallic connectors and the

buttons on the Arduino board - especially check from time to time that there are no crushes,

short circuits or unintentional button presses when the box is closed and screwed down.

Connect the ground wires (blue/black) together.

- Arduino board - TTGO ESP32 SX1276 LoRa 868 MHz without OLED-display:

https://www.aliexpress.com/item/4000025676352.html (<10,00€ / pcs.)

- GPS-modul NEO-6M: https://www.aliexpress.com/item/1872389528.html (3,55€ / pcs.)
- GSM-modul SIM800L with flat antenna:

https://www.aliexpress.com/item/32285159276.html (2,75€ / pcs.)

- 470µF 6,3V capacitors: Conrad (0,51€ / pcs.)
- resistors 470R 0,25W: Conrad (0,07€ / pcs.)

Version 3 of Heidi-Tracker:

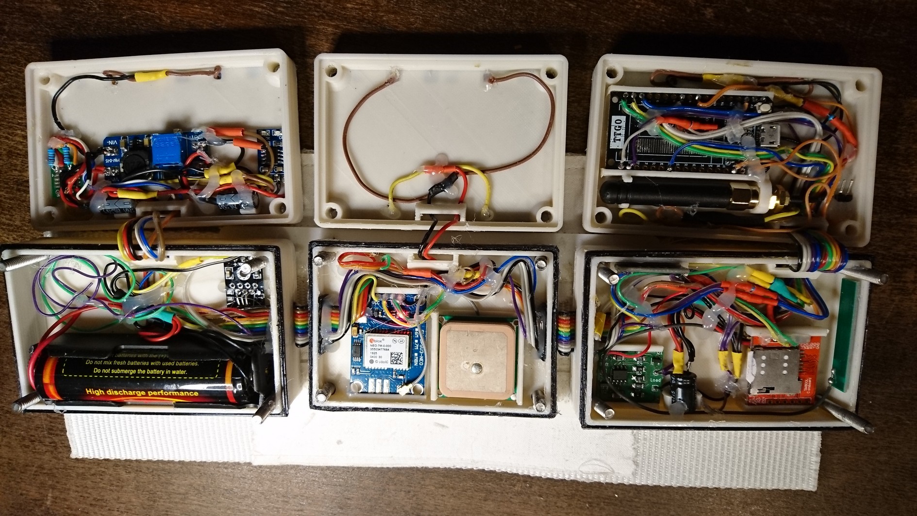
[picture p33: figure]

There is a new module near SIM800, which stabilizes the behavior of the Arduino board in case of very

a low battery. This is self made – means, you have to order the electronic parts and circuit board. The

board can be manufactured here (for a good price): https://aisler.net – the electronic parts may be

purchased here: https://www.conrad.de/ or https://www.reichelt.de/

The KiCad – project is uploaded to section “cad”: “SchmittTrigger” (KiCad: https://www.kicad.org/).

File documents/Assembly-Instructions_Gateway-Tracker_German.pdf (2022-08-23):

Für V3 bitte englische Dokumentation beachten.

Zusammenbau Gateway-Tracker Schaf-Variante

Die Gehäuseteile werden per 3D-Druck hergestellt.

Dabei muss für die Hartteile ASA-Filament

verwendet werden, um die Festigkeit und die

Witterungsbeständigkeit zu bekommen, die nötig

ist. PLA eignet sich definitiv nicht!

Die Dichtungsteile werden mit dauerelastischem

Filament gedruckt, z.B. SainSmart Flexible TPU.

Beide genannten Filament-Arten sind in der


Verarbeitung nicht ganz problemfrei und erfordern etwas Erfahrung.

Gehäuse Einzelteile - Unterseitenabdeckung für Solarpanel (DblSolarPltBottomCover) fehlt

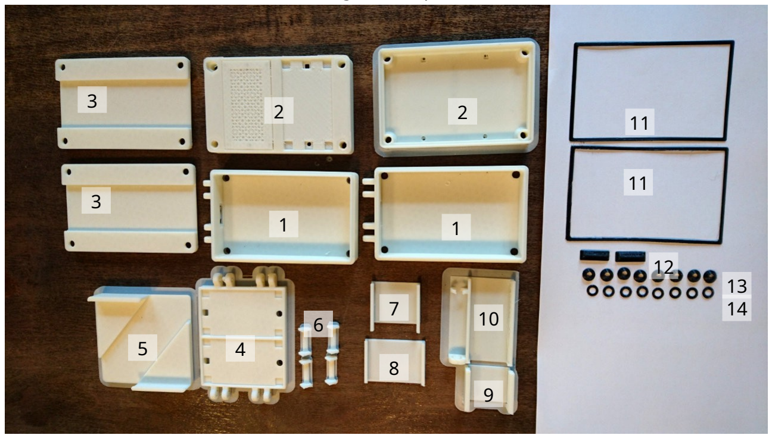
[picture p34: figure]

(1) Box Unterteil (BoxBottomGateway)
(2) Box Oberteil (BoxTopGateway)
(3) Längsgurtführung Box (BoxBeltClipGateway)
(4) Doppel-Solarpanel (DoubleSolarPlate)
(5) Quergurtführung Solar-Panel (DoubleSolarPlateBeltClip)
(6) Kabelführung (CableClip)
(7) GPS-Antennenhalterung (GPSAntennaClip)
(8) GPS-Boardhalterung (GPSBoardClip)
(9) GSM-Boardhalterung (GSMBoardClip)
(10) Arduino-Board-Halterung (ArduionoClip)
(11) Box-Dichtung (BoxGasket)
(12) Kabeltunnel-Dichtung (CableGasket)
(13) Senkkopfloch-Dichtung (ScrewHoleGasket)
(14) Schrauben-Dichtung (ScrewGasket)

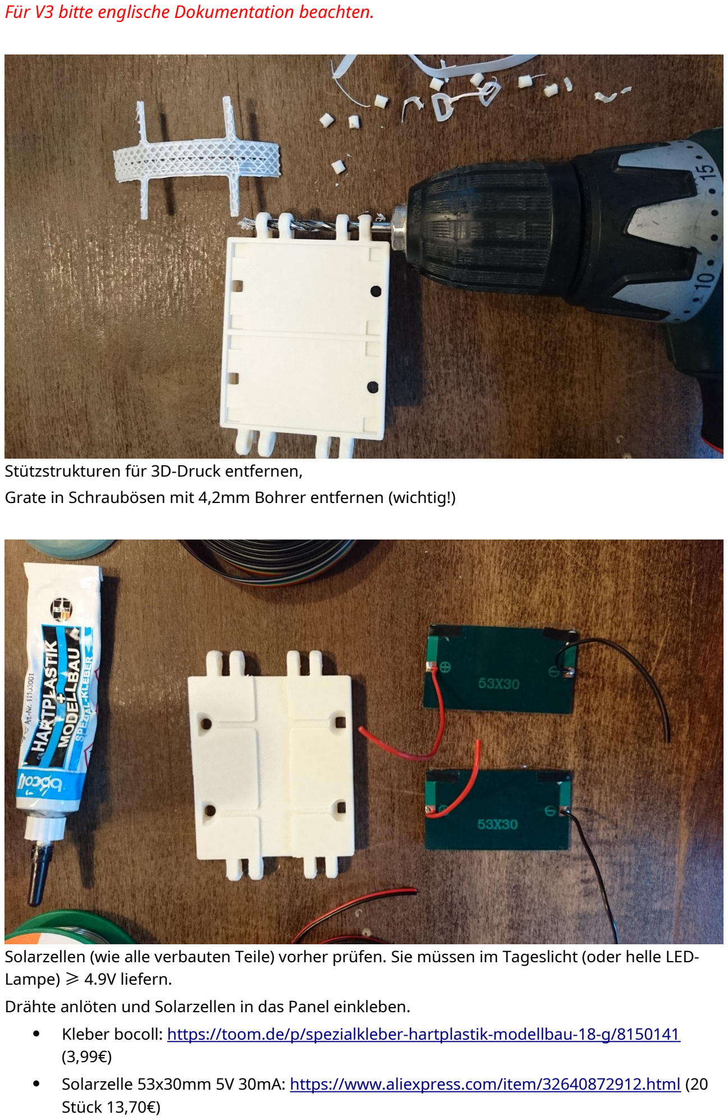
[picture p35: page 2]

Stützstrukturen für 3D-Druck entfernen,

Grate in Schraubösen mit 4,2mm Bohrer entfernen (wichtig!)

Solarzellen (wie alle verbauten Teile) vorher prüfen. Sie müssen im Tageslicht (oder helle LED-

Lampe) ≥ 4.9V liefern.

Drähte anlöten und Solarzellen in das Panel einkleben.

- Kleber bocoll: https://toom.de/p/spezialkleber-hartplastik-modellbau-18-g/8150141

(3,99€)

- Solarzelle 53x30mm 5V 30mA: https://www.aliexpress.com/item/32640872912.html (20

Stück 13,70€)

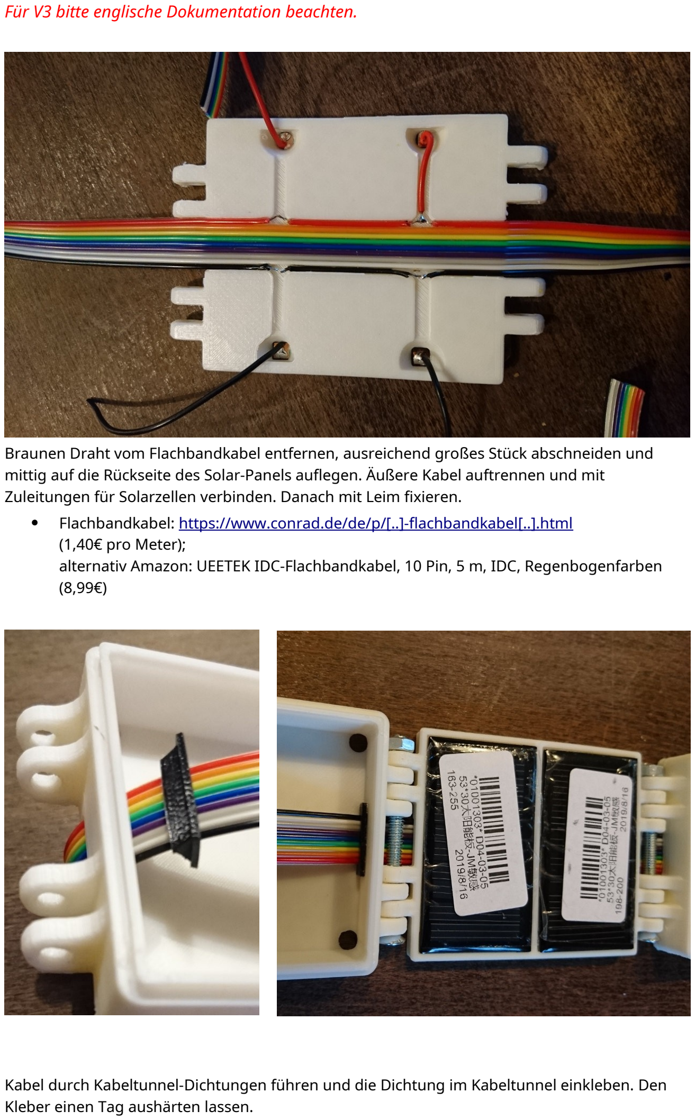
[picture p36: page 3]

Braunen Draht vom Flachbandkabel entfernen, ausreichend großes Stück abschneiden und

mittig auf die Rückseite des Solar-Panels auflegen. Äußere Kabel auftrennen und mit

Zuleitungen für Solarzellen verbinden. Danach mit Leim fixieren.

- Flachbandkabel: https://www.conrad.de/de/p/[..]-flachbandkabel[..].html (https://www.conrad.de/de/p/bkl-electronic-10120156-flachbandkabel-rastermass-1-27-mm-10-x-0-08-mm-bunt-744224.html)

(1,40€ pro Meter);

alternativ Amazon: UEETEK IDC-Flachbandkabel, 10 Pin, 5 m, IDC, Regenbogenfarben

(8,99€)

Kabel durch Kabeltunnel-Dichtungen führen und die Dichtung im Kabeltunnel einkleben. Den

Kleber einen Tag aushärten lassen.

Gehäuseunterteile und Solarpanel zusammensetzen mit M4x50.

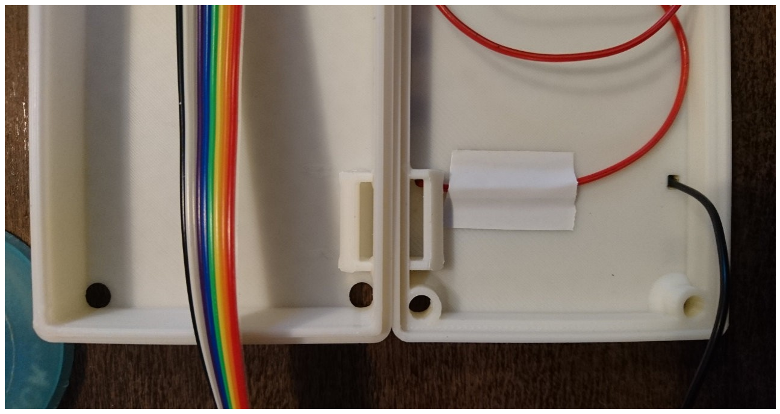
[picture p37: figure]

Gehäuseoberteile mit Solarzellen bestücken (genau wie Solarpanel, aber längere Zuleitungen)

Kabelführungen einkleben – für beide Seiten jeweils unterschiedliche Positionen, vergleiche

auch voll bestückte Gehäuseteile weiter unten. Den Kleber einen Tag aushärten lassen.

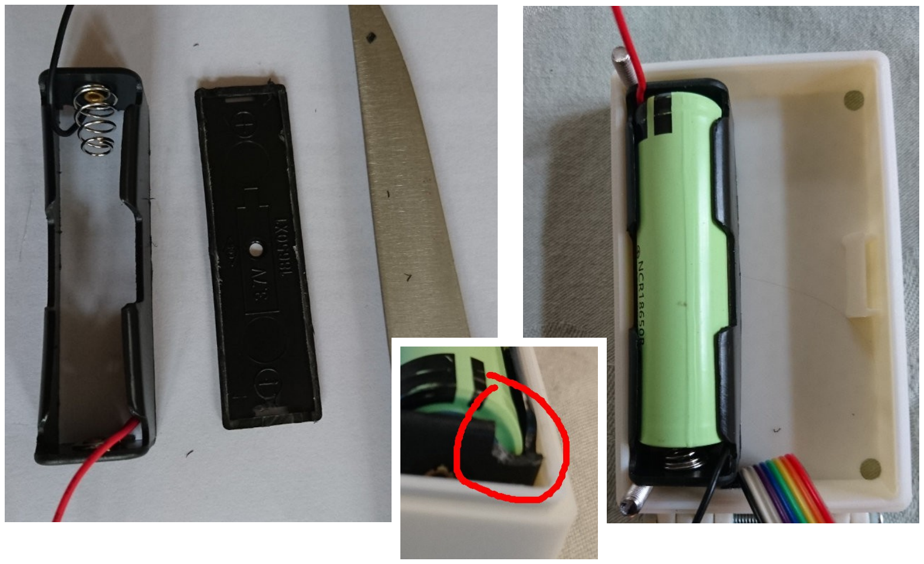
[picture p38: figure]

Kontakt der Zuleitung zum Batteriehalter prüfen – muss manchmal nachgelötet werden, weil die

Nietverbindung mangelhaft ist – es sollen später bis 3A in der Spitze darüber fließen, ohne

größere Spannungseinbrüche.

Boden vom Batteriefach entfernen (1,5mm Platzgewinn), hintere Seitenfläche aufrauen und

Batteriefach mit eingelegtem Akku und positionierten Gehäuse-Schrauben einkleben.

Äußere Stirnwandecken des Batteriefachs entfernen – sie kollidieren mit den Schraubdomen

(kleines Bild)

- 18650 Batteriefach: https://www.aliexpress.com/item/4000445340785.html (0,30€ / Stk.)

- Akku, Panasonic NCR18650B: viele Anbieter – nicht zu billig kaufen (ab 4,00€ / Stk.)


Die Lademodule und den DC-DC-Wandler in den Gehäuseoberteil einkleben und entsprechend

Schaltplan verdrahten.

Der DC-DC-Wandler sollte vor dem einkleben auf Uo=4 V eingestellt werden. Teilweise muss der

Stellwiderstand 1x komplett durchfahren werden.

Teilweise müssen die Kontaktdrähte der Durchsteckelemente an der Unterseite der

Leiterplatten abgeschliffen werden. Platz für den großen Akku beachten. Masseleitungen

(blau/schwarz) zu einem Ring verbinden.

- 2 x Micro USB 5V 1A 18650 TP4056 Lithium Battery Charger Module Charging Board With

Protection: https://www.aliexpress.com/item/32984862014.html (1,80€ / 10 Stk.)

- MT3608 DC-DC Step Up Converter Booster Power Supply Module Boost Step-up Board

https://www.aliexpress.com/item/32948417810.html (1,70€ / 5 Stk.)


AAA - Batteriefach aufrauen und mit eingelegtem Akku einkleben. Die TrustFire-Akkus sind

aufgrund der eingebauten Schutzschaltung etwas zu lang, passen und halten aber dennoch.

Möglich wären auch Akkus ohne Schutz, da das Lademodul hinreichend Schutz bietet, z.B. AAA

ICR 10440 bei amazon.

Von unten rechts nach links: die MOSFETs auf SOT23 Leiterplatten, die Schottky-Dioden auf einer

Rasterleiterplatte und der Thermosensor - entsprechend Schaltplan verdrahten.

- BestPlug Batteriehalter für Micro AAA Batterie, amazon: (2,16€ / Stk.)
- TrustFire Li-Ion Akku 3,7V AAA, amazon: (7,99€ / Stk.)
- Temperatursensor DS18B20 single-wire-bus digital temperature sensor module:

https://www.aliexpress.com/item/32242626689.html (0,80€ / Stk.)

- 2 x Schottky Diode 1N5817 Amazon: (4,99€ / 20 Stk.) - bei Vergleichstypen auf geringe

Forward Voltage achten

- MOSFETs - IRLML6402 SOT-23 Ultra Low On-Resistance P-Channel MOSFET, conrad:

(0,20€ / Stk.)

- SOT23 Leiterplatten, - MagiDeal 50 Stück 6 pin SOT23 TO DIP Adapter pcb: amazon

(3,99€ / 50 Stk)

- Leiterplatte Rastermaß 2,54 und Widerstände 4k7 0,25W bei Conrad (2,89 € / 75 cm² und

0,07€ / Stk.)


Alle Elektronik-Module in den vorgesehenen Halterungen einbauen und nach Schaltplan

verdrahten. Im Bild ist das GPS-Modul (oben Mitte) nicht in seiner Halterung, sondern direkt auf

das Gehäuse geklebt – das ist aufgrund der elektrischen Eigenschaften des Klebers

wahrscheinlich nicht gut und wurde später geändert.

Das verwendete Arduiono-Modul (unten) ist ein TTGO ESP32 SX1276 LoRa 868 MHz ohne OLED-

Display in der Version 1.7. Dazu einige Anmerkungen:

Es gibt neuere Varianten, die den Hardware-Hack (siehe nächster Absatz) nicht brauchen

oder die ggf. GPS gleich onboard haben. Das „alte“ Modul wurde dennoch ausgewählt, weil

es deutlich kostengünstiger ist und kompakt. Ferner sind die Position der USB-Buchse, die

Anbringung der LoRa-Antenne und ggf. die Anbringung der GPS-Antenne zu berücksichtigen

– alles in allem ist die gewählt Konfiguration die derzeit sinnvollste (Stand 06/2020).

Der Hardware-Hack (kleines Bild) ist erforderlich, weil sich in dieser Version des Boards der

USB-Serial-Converter nicht abschalten lässt und damit der Ruhestromverbrauch viel zu hoch

ist. Die Versorgung dieses IC wurde deshalb von der Bordspannung abgetrennt (getrennter

Leiterzug – vom linken Anschluss des IC in der oberen Bildmitte nach schräg links unten

zwischen die USB-Anschlüsse und den SMD-Widerstand) und die Spannungsversorgung

hinter der Trennung angelötet (violetter Draht am genannten IC) – mit angestecktem USB-

Kabel funktioniert der USB-Serial-Converter trotzdem.

Ein LoRa-Board wird nur gebraucht, wenn in der Herde ein lokales Netz mit Client-Trackern

zur Einzeltierüberwachung verwendet werden soll. Ansonsten ist jedes ESP32 Arduino-Board

mit ähnlichen Eigenschaften geeignet (z.B. WEMOS ESP-32 Lite V1.0.0 Development Board,

aliexpress: 3,50€).

Bei der Positionierung der Module auf die Leitungsführung, metallische Steckverbinder und die

Taster auf dem Arduino-Board achten – vor allem hin und wieder überprüfen, ob es beim

zuschrauben der Box nicht zu Quetschungen, Kurzschlüssen oder ungewollten Tasten-

Betätigungen kommt. Masseleitungen (blau/schwarz) zu einem Ring verbinden.

- Arduino Board - TTGO ESP32 SX1276 LoRa 868 MHz ohne OLED-Display:

https://www.aliexpress.com/item/4000025676352.html (<10,00€ pro Stck.)

- GPS-Modul NEO-6M: https://www.aliexpress.com/item/1872389528.html (3,55€ / Stk.)

- GSM-Modul SIM800L mit Flachantenne:

https://www.aliexpress.com/item/32285159276.html (2,75€ / Stk.)

- 2x 500µF 6,3V Elektrolytkondensatoren: bei Conrad (0,51€ / Stk.)
- Widerstände 470R 0,25W bei Conrad (0,07€ / Stk.)

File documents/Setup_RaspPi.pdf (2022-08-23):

## Setup RaspPi Heidi Server

- download / install RaspPi Imager from https://www.raspberrypi.org/software/
- > | rpi-imager | choose recommended image
- plug in SD card toRaspPi, login (user pi, passwd raspberry / raspberrz on german keyboards) startup, step through setup (no WiFi)
- resize root partition on SD-card to 16GiB (e.g. use gparted on a other system)
- backup and clean /opt
- create a separated fs mounted to /opt (best a separated device, a partition should do too)
- | remove auto-login: edit | /etc/lightdm/lightdm.conf | comment out line | autologin-user...
- | enable ssh | for remote sessions:

> sudo systemctl enable ssh

- install php, apache, mysql (mariadb)
> sudo apt install apache2 php mariadb-server | mariadb-client
> sudo systemctl enable mysql | (ignore „too many symlinks“)
> sudo mysql_secure_installation | (set new root pw/ all other „Y“)

> sudo mysql -u root
MariaDB [mysql]> USE mysql;
MariaDB [mysql]> UPDATE user SET plugin='mysql_native_password' WHERE User='root';
MariaDB [mysql]> FLUSH PRIVILEGES;
MariaDB [mysql]> exit;
- change store-location for mysql:

> sudo systemctl stop mariadb.service > sudo mkdir /opt/heidi
> sudo mv /var/lib/mysql /opt/heidi/.
> sudo chown -R mysql /opt/heidi/mysql
> sudo chgrp -R mysql /opt/heidi/mysql
> sudo nano /etc/mysql/mariadb.conf.d/50-server.cnf -> datadir = /opt/heidi/mysql
> sudo systemctl start mariadb.service
- | > sudo apt install phpmyadmin, | choose option apache2, do not reinstall database
- open phpmyadmin website and login with mariadb root login, phpmyadmin will request you to create basic structures
- new database: name „Heidi“ Kollation: utf8_general_ci
- new user: name „HeidiTracker“, localhost, INSERT / UPDATE / SELECT only on database „Heidi“
- create administrative user besides root with less privileges
- new Table „TrackerData“ InnoDB with 13 Columns (additionally you may add an auto-incremented primary key column):
TrackerID | VARCHAR | 9
Longitude | DECIMAL | 9,6
Latitude | DECIMAL | 9,6
Altitude | DECIMAL | 9,6
TimeStamp | DATETIME
Battery | DECIMAL | 3,2 | NULL
Temperature DECIMAL | 5,2 | NULL
FreeValue1 | VARCHAR | 16 | NULL
FreeValue2 | VARCHAR | 16 | NULL
FreeValue3 | VARCHAR | 16 | NULL
FreeValue4 | VARCHAR | 16 | NULL
FreeValue5 | VARCHAR | 16 | NULL
FreeValue6 | VARCHAR | 16 | NULL
FreeValue7 | VARCHAR | 16 | NULL
ErrorCode | VARCHAR | 16 | NULL
- new Table „Fence“ InnoDB with 4 Columns (additionally you may add an auto-incremented primary key column):
HerdeID | VARCHAR | 4
Longitude | DECIMAL | 9,6
Latitude | DECIMAL | 9,6
Active | TINYINT | Default: 0

- new Table „Settings“ InnoDB with 15 Columns (additionally you may add an auto-incremented primary key column):
HerdeID | VARCHAR 4
CyclesDay | INT 11 | Default: 4
CyclesNight | INT 11 | Default: 8
CycleLenDay | INT 11 | Default: 15
CycleLenNight | INT 11 | Default: 15
NightStartHour | INT 11 | Default: 20
NightEndHour | INT 11 | Default:6
DistAlarmThr | INT 11 | Default:500
AccThreshold1 | INT 11 | Default:100
AccThr1AlarmCnt INT 11 | Default:6000
AccThreshold2 | INT 11 | Default:200
AccThr2AlarmCnt INT 11 | Default:6000
accNightFactor | INT 11 | Default:1
TelNo1 | VARCHAR 32
TelNo2 | VARCHAR 32

- configure apache2 for web-frontend
/etc/apache2/ports.conf: add ports for http and https / tls (I‘m using 1080 for http and 1083 for https you may use other ports)

>sudo nano /etc/apache2/apache2.conf

## (additionally to similar blocks) add:

<Directory /opt/heidi/web/>
Options Indexes FollowSymLinks AllowOverride None
Require all granted
</Directory>

>sudo nano /etc/apache2/sites-available/heidi.conf <VirtualHost *:1080>
| ServerAdmin root@localhost
| DocumentRoot /opt/heidi/web
| ErrorLog ${APACHE_LOG_DIR}/error.log
| CustomLog ${APACHE_LOG_DIR}/access.log combined
</VirtualHost>

> sudo nano /etc/apache2/sites-available/heidi-ssl.conf <IfModule mod_ssl.c>
<VirtualHost *:1083>
ServerAdmin root@localhost DocumentRoot /opt/heidi/web

ErrorLog ${APACHE_LOG_DIR}/error.log
CustomLog ${APACHE_LOG_DIR}/access.log combined

SSLEngine on
SSLCertificateFile | /etc/ssl/certs/ssl-cert-snakeoil.pem
SSLCertificateKeyFile /etc/ssl/private/ssl-cert-snakeoil.key

<FilesMatch "\.(cgi|shtml|phtml|php)$">
SSLOptions +StdEnvVars
</FilesMatch>
<Directory /usr/lib/cgi-bin> SSLOptions +StdEnvVars
</Directory>

</VirtualHost>
</IfModule>
(copy details from default-ssl.conf)

> sudo a2ensite heidi.conf
> sudo a2ensite heidi-ssl.conf
> sudo a2enmod ssl
> sudo systemctl restart apache2.service
- | you may need to manually upgrade phpmyadmin, following: | https://devanswers.co/manually-upgrade-
| phpmyadmin/ (https://devanswers.co/manually-upgrade-phpmyadmin/)
- Web-contend: upload all files from repository to /opt/heidi/web, enter /opt/heidi/web
> wget https://github.com/openlayers/ol2/releases/download/release-2.13.1/
| OpenLayers-2.13.1.tar.gz > tar -xvzf OpenLayers-2.13.1.tar.gz > mv OpenLayers-2.13.1 ol > rm OpenLayers-2.13.1.tar.gz

### - Configure your network according to the settings made here. If you not intend to use a

### commercial web-service, which maybe not a bad idea, you may use a fritz box DSL router

| because AVM provides a static URL for each device.

## - that‘s it

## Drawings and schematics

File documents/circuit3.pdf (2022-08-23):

## Mid Box →

# Power Box

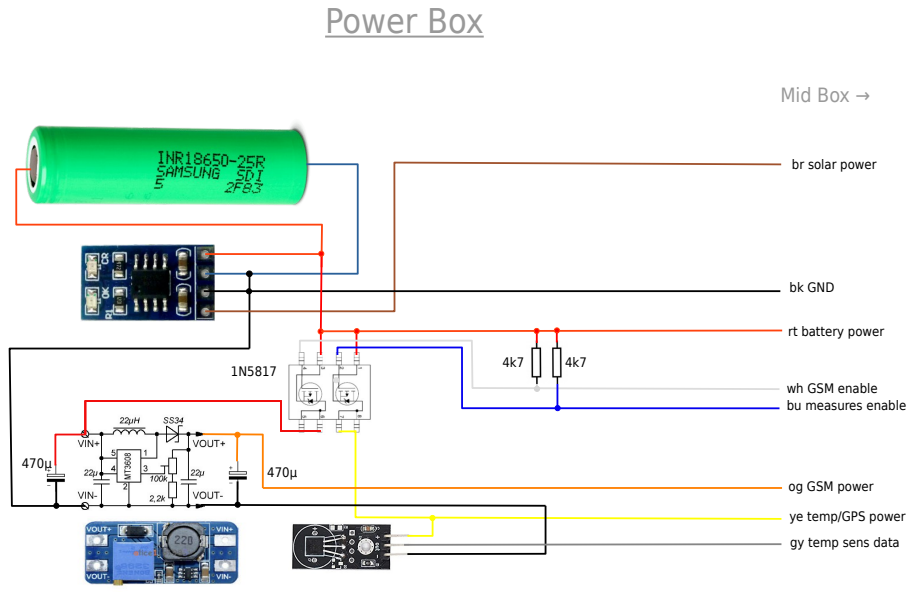
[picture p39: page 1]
bk GND

br solar power

rt battery power

wh GSM enable
bu measures enable

og GSM power

ye temp/GPS power

gy temp sens data

# Mid Box

← Power Box | Arduino Box →

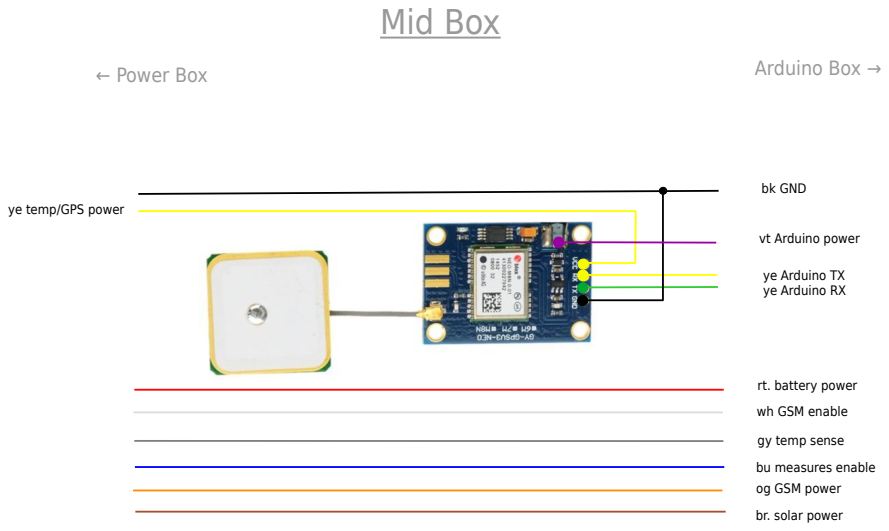
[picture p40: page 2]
bk GND

ye temp/GPS power

vt Arduino power

ye Arduino TX
ye Arduino RX

rt. battery power

wh GSM enable

gy temp sense

bu measures enable
og GSM power

br. solar power

Arduino Box | Mid Box →

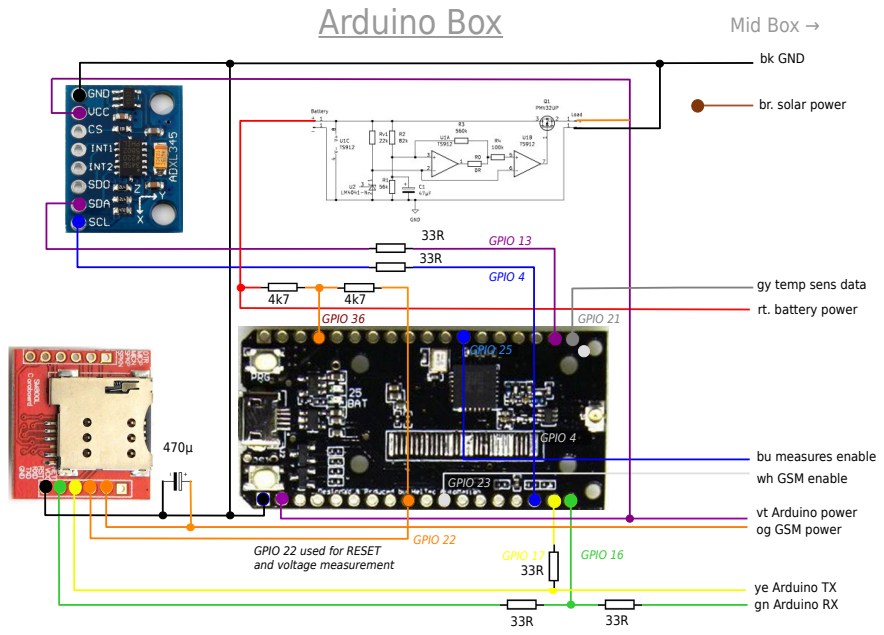
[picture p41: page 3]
bk GND; GPIO 17; GPIO 16; GPIO 4; GPIO 13; GPIO 36; GPIO 23; GPIO 25; GPIO 21; GPIO 22

br. solar power

gy temp sens data

rt. battery power

bu measures enable
wh GSM enable

vt Arduino power
og GSM power

GPIO 22 used for RESET
and voltage measurement

ye Arduino TX
gn Arduino RX

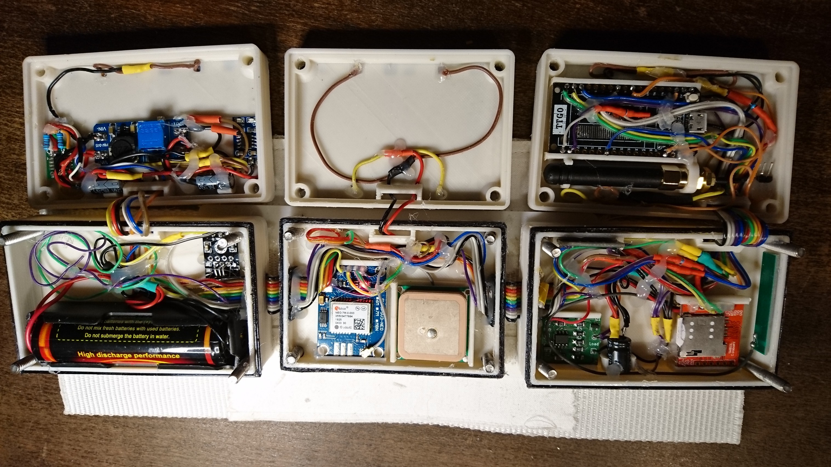
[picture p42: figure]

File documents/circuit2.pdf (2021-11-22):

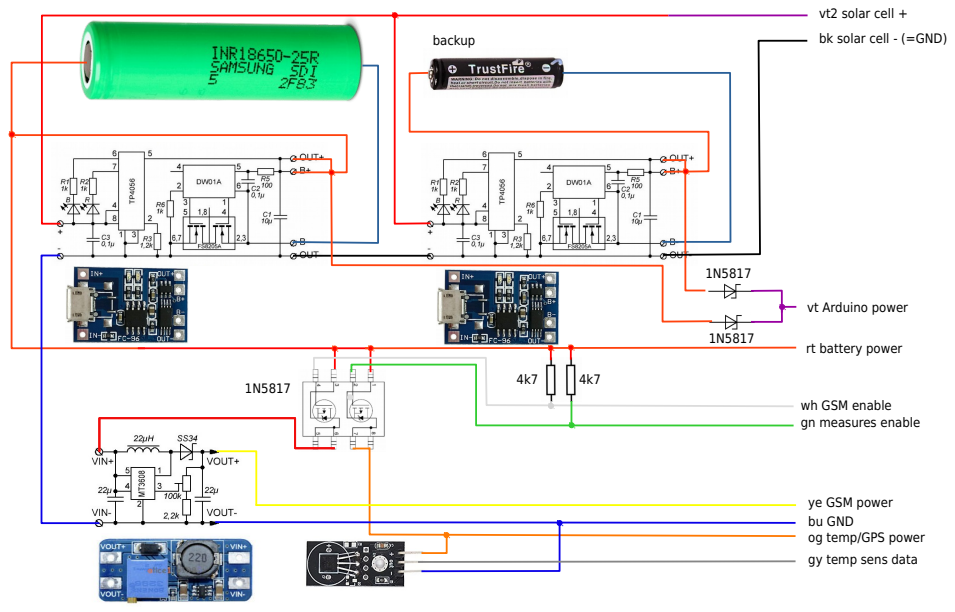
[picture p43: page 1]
backup

vt2 solar cell +
bk solar cell - (=GND)

vt Arduino power

rt battery power

wh GSM enable
gn measures enable

ye GSM power
bu GND
og temp/GPS power
gy temp sens data

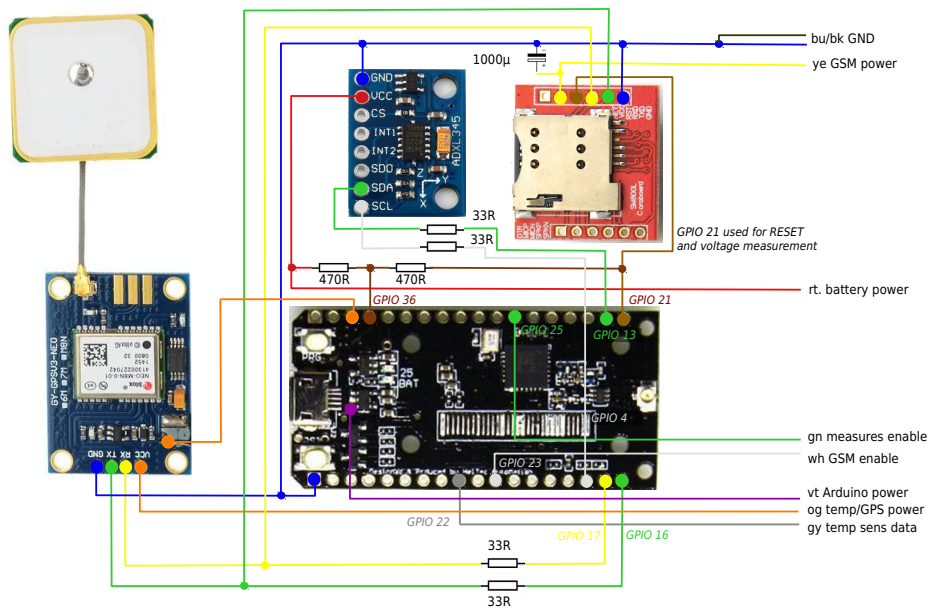
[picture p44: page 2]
GPIO 17; GPIO 16; GPIO 4; GPIO 13; GPIO 22; GPIO 36; GPIO 23; GPIO 25; GPIO 21

bu/bk GND
ye GSM power

GPIO 21 used for RESET
and voltage measurement

rt. battery power

gn measures enable
wh GSM enable

vt Arduino power
og temp/GPS power
gy temp sens data

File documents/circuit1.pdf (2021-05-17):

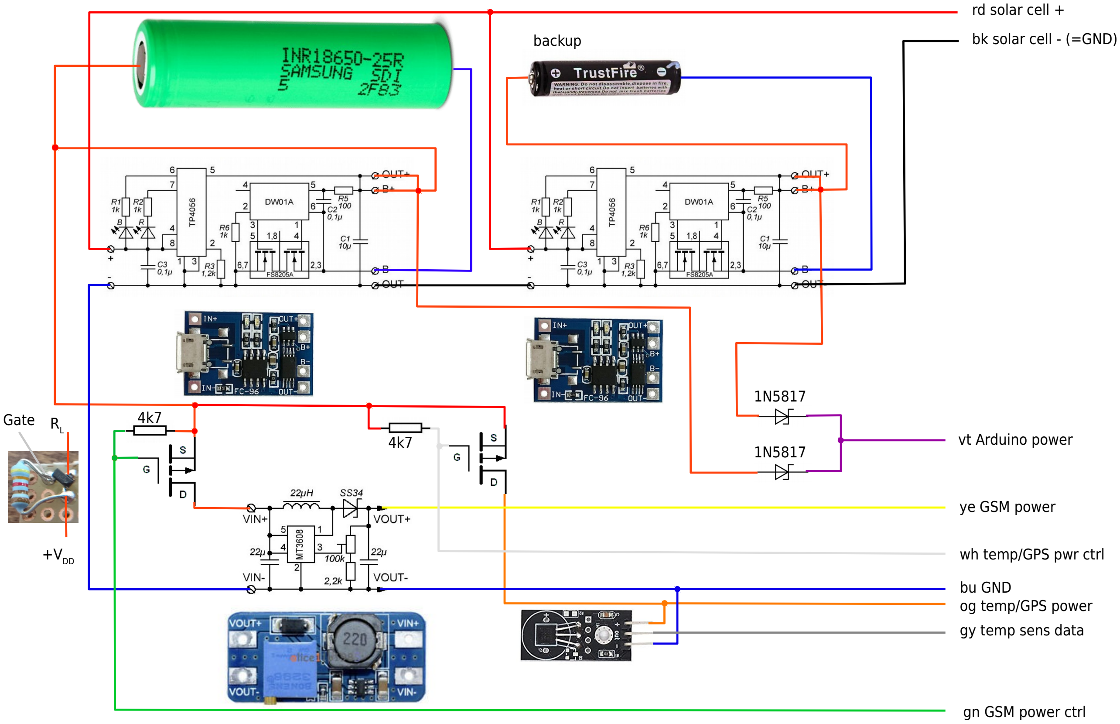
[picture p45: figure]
rd solar cell +; bk solar cell - (=GND); gn GSM power ctrl; gy temp sens data; bu GND; og temp/GPS power; wh temp/GPS pwr ctrl; ye GSM power; vt Arduino power; backup; +VDD; Gate
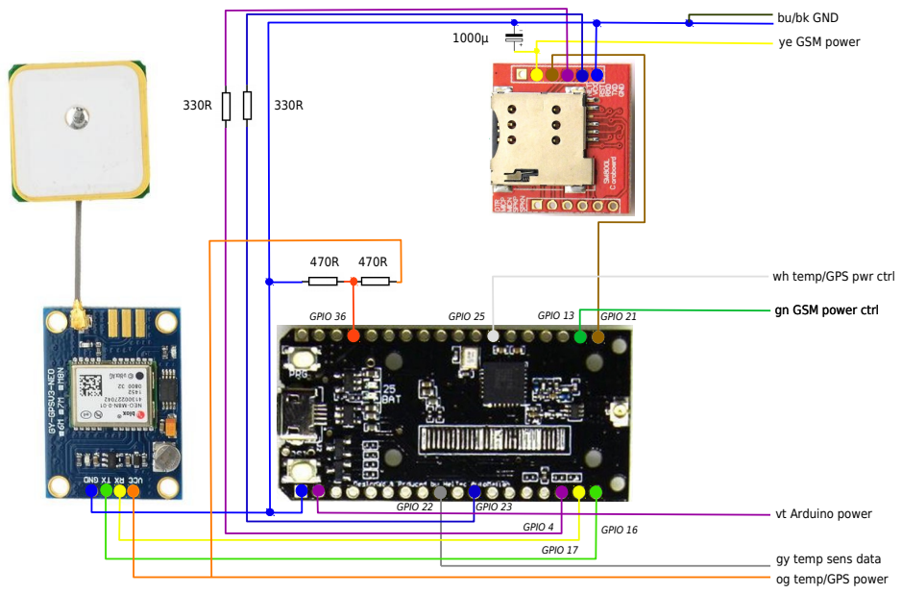
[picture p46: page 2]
GPIO 21; gn GSM power ctrl GPIO 36; GPIO 25; GPIO 13; GPIO 16; GPIO 17; GPIO 4; GPIO 22; GPIO 23

bu/bk GND
ye GSM power

wh temp/GPS pwr ctrl

gn GSM power ctrl

vt Arduino power

gy temp sens data
og temp/GPS power

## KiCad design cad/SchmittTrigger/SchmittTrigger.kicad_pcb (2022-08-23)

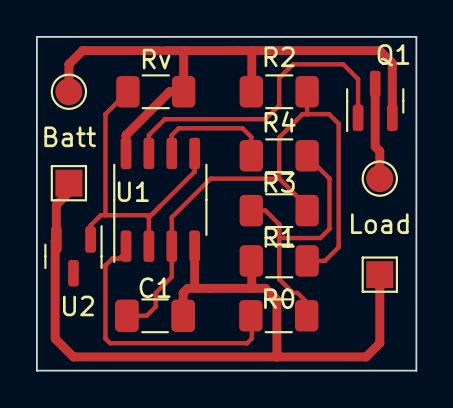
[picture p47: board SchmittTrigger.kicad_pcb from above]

Board: 2 copper layers, 21.1 x 18.5 mm, 14 parts (0 on the bottom side), 9 nets.

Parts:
-1: Battery; TestPoint_Pad_1.5x1.5mm
Batt: +; TestPoint_Pad_D1.5mm
C1: 10µF; C_1206_3216Metric_Pad1.33x1.80mm_HandSolder
Load: +; TestPoint_Pad_D1.5mm
Load2: -; TestPoint_Pad_1.5x1.5mm
Q1: PMV32UP; SOT-23
R0: 0R; R_1206_3216Metric_Pad1.30x1.75mm_HandSolder
R1: 56k; R_1206_3216Metric_Pad1.30x1.75mm_HandSolder
R2: 82k; R_1206_3216Metric_Pad1.30x1.75mm_HandSolder
R3: 560k; R_1206_3216Metric_Pad1.30x1.75mm_HandSolder
R4: 100k; R_1206_3216Metric_Pad1.30x1.75mm_HandSolder
Rv: 22k; R_1206_3216Metric_Pad1.30x1.75mm_HandSolder
U1: TS912; SO-8_3.9x4.9mm_P1.27mm
U2: LM4041-N; SOT-23

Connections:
GND: -1.1, C1.2, Load2.1, R1.1, U1.4 (V-), U2.2 (A)
unnamed: Batt.1, Q1.2 (S), R2.2, Rv.1, U1.8 (V+)
unnamed: C1.1, R1.2, R2.1, R3.1, U1.3 (+)
unnamed: Load.1, Q1.3 (D)
unnamed: Q1.1 (G), U1.7
unnamed: R0.1, R3.2, R4.2
unnamed: R0.2, U1.1
unnamed: R4.1, U1.6 (-)
unnamed: Rv.2, U1.2 (-), U1.5 (+), U2.1 (K)

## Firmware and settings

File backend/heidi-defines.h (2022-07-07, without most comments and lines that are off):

#include "heidi-secrets.h"
#define HEIDI_DEFINES_H_
#define HEIDI_CONFIG_3
#ifdef HEIDI_CONFIG_1
#define HEIDI_SW_BRAND              1
#define HEIDI_HERDE                 1
#define USE_HEIDI_CONFIG_1_PINS
#define GPS_MODULE
#define USE_CASIC_GPS
#define USE_LORA
#define TEMP_SENSOR
#define CHECK_BATTERY
#define USE_RTC_FAST_MEM
#define DEFAULT_BOOT_CYCLES         12        // cycles until transferring data
#define DEFAULT_CYCLE_DURATION      15        // minutes
#define MAX_AWAKE_TIME_POWER        3         // minutes 0 = infinite
#define MAX_AWAKE_TIME_TIMER        2         // minutes 0 = infinite
#define DEFAULT_DIST_ALERT_THRES    100       // meters
#endif
#ifdef HEIDI_CONFIG_2
#define HEIDI_SW_BRAND              2
#define LORA_V1_3_OLED
#define USE_HEIDI_CONFIG_2_PINS
#define HEIDI_HERDE                 1
#define GPS_MODULE
#define COMMON_SERIAL
#define TEMP_SENSOR
#define CHECK_BATTERY
#define USE_VOLT_MEAS_EN_PIN
#define I2C_BUS
#define ACCELEROMETER
#define USE_ULP
#define USE_GPS_ALERT
#define USE_LORA
#define USE_RTC_FAST_MEM
#define DEFAULT_BOOT_CYCLES         12        // cycles until transferring data
#define DEFAULT_CYCLE_DURATION      15        // minutes
#define MAX_AWAKE_TIME_POWER        3         // minutes 0 = infinite
#define MAX_AWAKE_TIME_TIMER        2         // minutes 0 = infinite
#define DEFAULT_DIST_ALERT_THRES    100       // meters
#endif
#define HEIDI_SW_BRAND              3
#define LORA_V1_3_OLED
#define USE_HEIDI_CONFIG_3_PINS
#define HEIDI_HERDE                 1
#define GPS_MODULE
#define COMMON_SERIAL
#define TEMP_SENSOR
#define CHECK_BATTERY
#define USE_VOLT_MEAS_EN_PIN
#define I2C_BUS
#define ACCELEROMETER
#define USE_ULP
#define USE_GPS_ALERT
#define USE_LORA
#define USE_RTC_FAST_MEM
#define DEFAULT_BOOT_CYCLES         4         // cycles until transferring data
#define DEFAULT_CYCLE_DURATION      15        // minutes
#define MAX_AWAKE_TIME_POWER        3         // minutes 0 = infinite
#define MAX_AWAKE_TIME_TIMER        2         // minutes 0 = infinite
#define DEFAULT_DIST_ALERT_THRES    100       // meters
#ifdef HEIDI_CONFIG_TEST
#define HEIDI_SW_BRAND              0
#define HEIDI_HERDE                 1
  #define USE_HEIDI_CONFIG_2_PINS
  #define LORA_V1_1_OLED
  #define GPS_MODULE
  #define COMMON_SERIAL
  #define TEMP_SENSOR
  #define USE_LORA
  #define USE_VOLT_MEAS_EN_PIN
  #define I2C_BUS
  #define ACCELEROMETER
  #define USE_ULP
#define DEFAULT_BOOT_CYCLES         3        // ..until transferring data
#define DEFAULT_CYCLE_DURATION      10       // minutes
#define MAX_AWAKE_TIME_POWER        3        // minutes 0 = infinite
#define MAX_AWAKE_TIME_TIMER        2        // minutes 0 = infinite
#define DEFAULT_DIST_ALERT_THRES    100      // meters
#endif
                    #define NO_TESTS
#define HEIDI_MAX_CLIENTS  32   //currently not more than 32 are supported because they are represented in a uint32_t bitmap
#define HEIDI_GATEWAY_ADDRESS 1 //address 0 = not set = empty data set
#define HEIDI_FIRST_CLIENT 2
#define MAX_DATA_SETS_PER_SEND_LINE 96
#define HEIDI_ANIMAL        HEIDI_FIRST_CLIENT+1
#define MIN_FREE_SETS_FOR_REQUEST  100
#define MIN_CYCLE_DURATION          5         //  5 minutes
#define MAX_CYCLE_DURATION          60        //  1 hour
#define MAX_CYCLES_PER_DAY          288       //  5 minutes each a cycle + 2 fix points - but if we have 5 minutes each a cycle, the fix points will meet a cycle
#define PRE_CYCLE_TIME              30000     //  wake GPS 30 seconds before measuring (PRE_MEASURE_HANDLINg)
#define MAX_BOOT_CYCLES             (MAX_DATA_SETS >> 1) // ..until transferring data = half count of data sets
#define MAX_MEAS_TIME               5000      //  5 seconds
#define MAX_FAILED_ALERTS           10        //  abort alerting after 10 fails
#define START_FROM_RESET     -2
#define REFETCH_SYS_TIME     -1
#define FIRST_REGULAR_CYCLE  0
#define INVALID_TIME_VALUE   -1
#define S_TO_mS_FACTOR      1000
#define uS_TO_S_FACTOR      1000000
#define uS_TO_mS_FACTOR     1000
#define SLEEP_DUR_NOTIME    300000
#define SLEEP_DUR_ALERT     300000
#define MIN_SLEEP_TIME_MS   1000
#define MAX_SLEEP_TIME_MS   (MAX_CYCLE_DURATION * 60000)
#define ONE_MINUTE          60000
#define MS_PER_DAY          86400000
#define FIX_POINT_MIN_MS    15000     //15 sec. minimum fix point duration
#define HEIDI_EARLIER_WAKEUP_S 3 //3 sec. earlier wake up
#define HEIDI_EARLIER_WAKEUP_MS (HEIDI_EARLIER_WAKEUP_S * S_TO_mS_FACTOR)
#define LORA_MAX_ONAIR_TIME_MS  (45000 + HEIDI_EARLIER_WAKEUP_MS) //must be less than 1 minute with a little guard time
#define MAX_AWAKE_TIME_POWER_MSEC (MAX_AWAKE_TIME_POWER * ONE_MINUTE)
#define MAX_AWAKE_TIME_TIMER_MSEC (MAX_AWAKE_TIME_TIMER * ONE_MINUTE)
#define AWAKE_TM_TRANSMIT_MSEC_OFFS ONE_MINUTE
#define DEFAULT_CYCLE_DURATION_MSEC (DEFAULT_CYCLE_DURATION * ONE_MINUTE)
#if (MAX_AWAKE_TIME_POWER_MSEC == 0) || (MAX_AWAKE_TIME_TIMER_MSEC == 0)
#pragma warning "timeout disabled!"
#endif
#define DEFALUT_NIGHT_HOUR_START_UTC    0
#define DEFALUT_NIGHT_HOUR_END_UTC      0
#define FIXPOINT_1_UTC 6
#define FIXPOINT_2_UTC 18
#ifdef HEIDI_CONFIG_TEST
#define DEFALUT_ACCELERATION_THRESHOLD_1    50
#define DEFALUT_ACCELERATION_THRESHOLD_2   150
#define DEFALUT_ACCEL_THRES_MAX_COUNT_1   16000
#define DEFALUT_ACCEL_THRES_MAX_COUNT_2   16000
#else
#define DEFALUT_ACCELERATION_THRESHOLD_1  100
#define DEFALUT_ACCELERATION_THRESHOLD_2  250
#define DEFALUT_ACCEL_THRES_MAX_COUNT_1   16000
#define DEFALUT_ACCEL_THRES_MAX_COUNT_2   16000
#endif
#ifdef NO_STEP_UP_CONV
#define GSM_POWER_SAVE_1_VOLTAGE    3.8   //double transmission time
#define GSM_POWER_SAVE_2_VOLTAGE    3.7   //no more transmissions
#define GSM_POWER_SAVE_3_VOLTAGE    3.3   //do nothing just deep sleep
#define GSM_POWER_SAVE_4_VOLTAGE    3.2   //do nothing deep sleep for 1 hour
#else
#define GSM_POWER_SAVE_1_VOLTAGE    3.6   //double transmission time
#define GSM_POWER_SAVE_2_VOLTAGE    3.4   //no more transmissions
#define GSM_POWER_SAVE_3_VOLTAGE    3.3   //do nothing just deep sleep
#define GSM_POWER_SAVE_4_VOLTAGE    3.2   //do nothing deep sleep for 1 hour
#endif
typedef enum _heidiStatus_t {
  PRE_MEAS_STATE      = 0x00000001,
  PRE_GPS_ALERT       = 0x00000002,
  GPS_ALERT_1         = 0x00000004,
  GPS_ALERT_2         = 0x00000008,
  GPS_ALERT_PSD       = 0x00000010, //alert passed
  PRE_ACC_ALERT       = 0x00000020,
  ACC_ALERT_1         = 0x00000040,
  ACC_ALERT_2         = 0x00000080,
  ACC_ALERT_PSD       = 0x00000100,
  POWER_SAVE_1        = 0x00000200,
  POWER_SAVE_2        = 0x00000400,
  NOT_IN_CYCLE        = 0x00000800,
  NEW_FENCE           = 0x00001000,
  NEW_SETTINGS        = 0x00002000,
  NEW_ACC_DATA        = 0x00004000,
  RESET_INITS         = 0x00008000,
  TRSMT_DATA_ERROR    = 0x00010000,
  ULP_RUNNING         = 0x00020000,
  FROM_PWR_SAVE_SLEEP = 0x00040000,
  IS_FIX_POINT        = 0x00080000
}heidiStatus_t;
#ifdef HEIDI_CONFIG_1
#ifdef HEIDI_CONFIG_2
#error "HEIDI_1 and HEIDI_2 enabled"
#endif
#endif
#ifdef HEIDI_CONFIG_1
#error "HEIDI_1 and HEIDI_3 enabled"
#endif
#ifdef HEIDI_CONFIG_2
#error "HEIDI_2 and HEIDI_3 enabled"
#endif
#ifdef HEIDI_CONFIG_1
#ifdef HEIDI_CONFIG_TEST
#error "HEIDI_TEST and HEIDI_1 enabled"
#endif
#endif
#ifdef HEIDI_CONFIG_2
#ifdef HEIDI_CONFIG_TEST
#error "HEIDI_TEST and HEIDI_2 enabled"
#endif
#endif
#ifdef HEIDI_CONFIG_TEST
#error "HEIDI_TEST and HEIDI_3 enabled"
#endif
#ifdef USE_HEIDI_CONFIG_1_PINS
#ifdef USE_HEIDI_CONFIG_2_PINS
#error "GPIO configuration clash"
#endif
#endif
#ifdef USE_HEIDI_CONFIG_1_PINS
#error "GPIO configuration clash"
#endif
#ifdef USE_HEIDI_CONFIG_2_PINS
#error "GPIO configuration clash"
#endif
#ifdef ACCELEROMETER
#ifndef I2C_BUS
#error "I2C bus for accelerometer not enabled"
#stop
#endif
#ifndef USE_ULP
#error "ULP for accelerometer not enabled"
#endif
#endif
#ifdef USE_ULP
#ifndef ACCELEROMETER
#error "No accelerometer for ULP measurement"
#endif
#endif
#ifdef I2C_BUS
#ifndef COMMON_SERIAL
#error "I2C and 2nd UART does not work together"
#endif
#endif
#ifndef GPS_MODULE
#error "No GPS module -> no GPS alert"
#endif
#ifdef USE_OLED
#define USE_NO_MEASURES
#endif
#ifndef HEIDI_CONFIG_TEST
#if (MAX_AWAKE_TIME_POWER_MSEC == 0) || (MAX_AWAKE_TIME_TIMER_MSEC == 0)
#error "Timeout disabled!"
#endif
#ifdef USE_OLED
#error "Use OLED display for tests only"
#endif
#ifdef USE_NO_MEASURES
#error "USE_NO_MEASURES for tests only"
#endif
#endif //#ifndef HEIDI_CONFIG_TEST
#ifndef HEIDI_HERDE
#error "Please set a default value."
#endif
#ifndef HEIDI_SERVER_PUSH_URL
#error "Please set a default value."
#endif
#ifndef HEIDI_MOBILE_APN
#error "Please set a default value."
#endif
#ifndef HEIDI_MOBILE_USER
#error "Please set a default value."
#endif
#ifndef HEIDI_MOBILE_PASSWD
#error "Please set a default value."
#endif
#ifndef HEIDI_SIM_PIN
#error "Please set a default value."
#endif
extern bool GPSenabled;
extern bool GSMenabled;
extern bool MEASenabled;
extern bool CTLenabled;
extern bool VOLTenabled;

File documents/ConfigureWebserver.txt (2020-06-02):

edit /etc/apache2/ports.conf:
    Listen 1080
    Listen 1083 https

    <IfModule ssl_module>
            Listen 1083
    </IfModule>

    <IfModule mod_gnutls.c>
            Listen 1083
    </IfModule>

edit /etc/apache2/sites-available/*.conf
 on     "<VirtualHost *.[PORT]>" set [PORT]
 set    "DocumentRoot" 
 insert "DirectoryIndex home.html index.html start.php"

#apply
$> sudo a2enmod ssl
$> sudo systemctl restart apache2

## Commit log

2018-12-29 filter changes
2019-03-13 add some Doku
    [Datarate.ods]
2020-06-02 initial power management
2020-06-02 add cad
    [.stl, ArduinoClip.fcstd, ArduinoClip.stl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]
2020-06-05 some cad corrections
    [BoxTopGateway.fcstd, BoxTopGateway.stl, DblSolarPltBeltClipSheet.stl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]
2020-06-10 add assembly instructions
2020-06-18 update assembly instructions
    [DblSolarPltBottomCover.fcstd]
2021-03-22 add accelerometer measurements and i2c switch
    [BoxBottomGateway2.fcstd, BoxTopGateway2.fcstd, CableGasket2.fcstd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]
2021-05-17 final version 2 with accelerometer
    [12mmBoardClip.stl, 12mmClip.FCStd, 21mmBoardClip.stl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]
2021-05-17 remove circuit.pdf
2021-05-20 fix alert state behavior
    [heidi-defines.h, heidi-gps.cpp, heidi-gsm.cpp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]
2021-06-15 add power-management documentation
2021-10-14 some bugfixes
    [GPSAntennaClip.fcstd]
2021-10-14 cleanup repository
    [Datarate.ods]
2021-10-14 remove old files from repository
    [CE3_BoxBeltClipGateway.3mf, CE3_BoxBottomGateway.3mf, CE3_CableGasket.3mf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]
2021-11-22 enable accelerometer during measuring
2021-11-22 wrong compiler switch
2021-12-30 bugfixes, initial config interface, RTC fast mem usage
    [heidi-acc.cpp, heidi-acc.h, heidi-data.h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]
2022-01-12 new positioning procedure / bugfixes
    [heidi-data.h, heidi-debug.cpp, heidi-defines.h]
2022-01-22 add cad readme
2022-01-22 updat cad/readme.md
2022-01-22 test cad/readme.md
2022-01-30 fix serious problem with data handling
    [heidi-data.h]
2022-03-18 backend: add threadsave data access, frontend: check data before pushing it to database
2022-03-18 change getNextnDataSets, fix data access deadlock
    [heidi-data.h]
2022-03-31 update cad files
    [13mmBoardClip.stl, ArduinoClip3.fcstd, ArduinoClip3.stl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]
2022-03-31 remove old cad files
    [BoxBottomGateway2.fcstd, BoxBottomGateway2.stl, BoxTopGateway2.fcstd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]
2022-04-21 new gasket design
    [BoxGasket.fcstd, BoxGasket.stl, BoxGasket3.fcstd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]
2022-04-21 Delete .stl
    remove garbage
    [.stl]
2022-04-21 halt ULP during GSM transmission / bugfixes
    [heidi-acc.cpp, heidi-debug.cpp, heidi-defines.h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]
2022-04-28 change solar plate to mid box
    [BoxBottomGateway.fcstd, DoubleSolarPlateBottom.fcstd, DoubleSolarPlateBottom.stl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]
2022-05-30 change temperature measurement
2022-08-23 add PCB, update docs
    [SchmittTrigger.kicad_pcb, SchmittTrigger.kicad_sch]
